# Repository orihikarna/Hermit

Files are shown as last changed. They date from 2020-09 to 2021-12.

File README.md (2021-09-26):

# Hermit - An Ergonomic Narrow-Pitch Split Keyboard

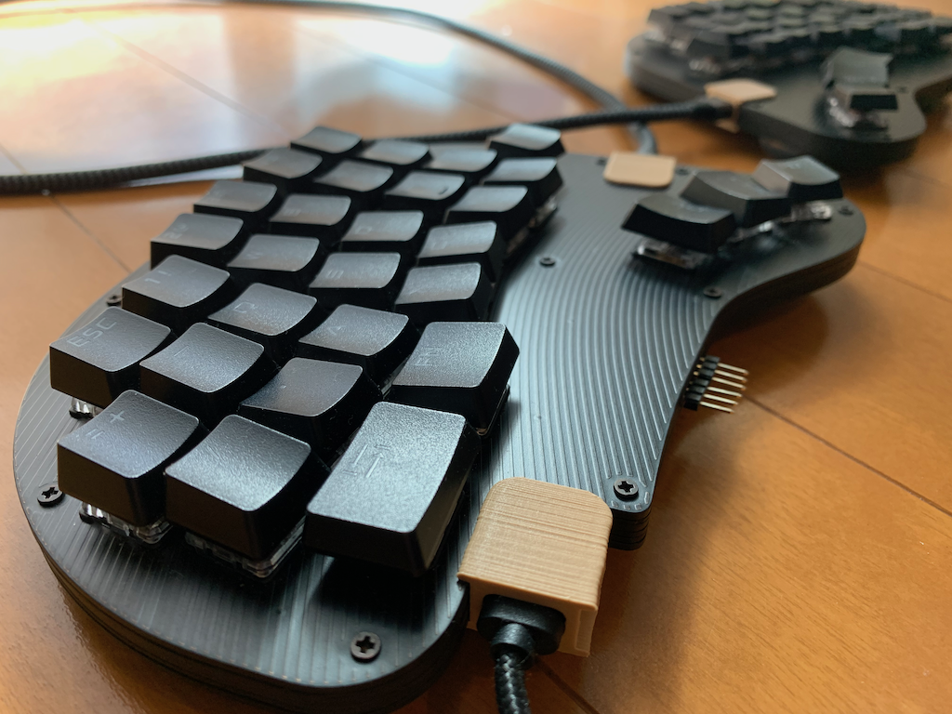
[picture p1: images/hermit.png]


## Introduction
This is a personal hobby project on DIY keyboard.
The name *Hermit* comes from its key switch layout: it looked like a hermit crab.

Before working on this "full" keyboard, I made a test split keypad with 10 keys as a proof of concept model, which was named *Zoea*.

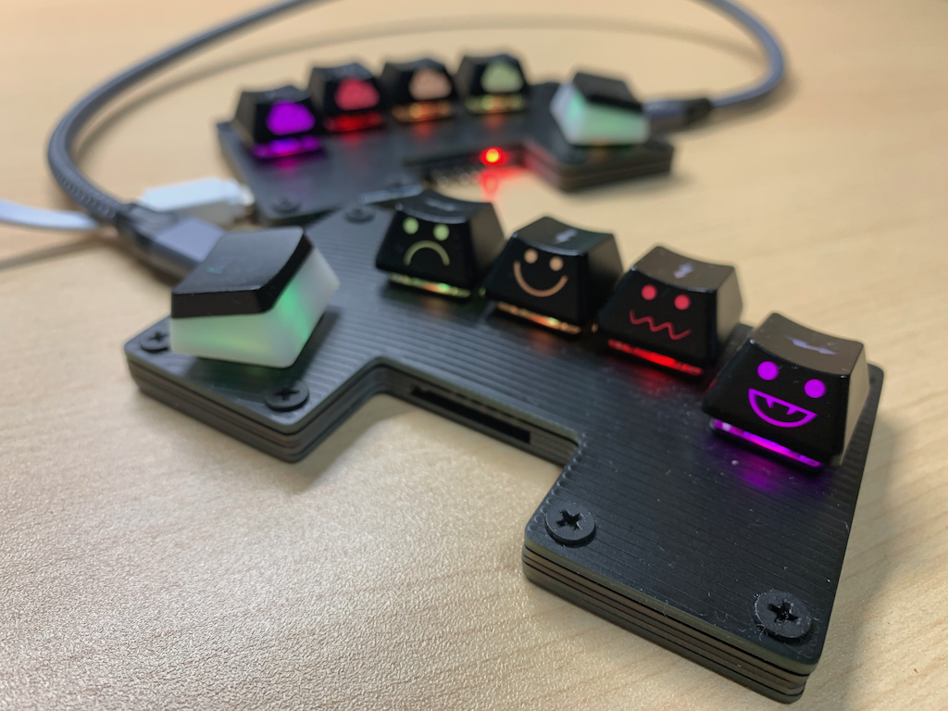
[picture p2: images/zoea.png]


### Features
- Symmetric split with 60 keys
  - Key switch: Choc V2
  - Narrow pitch: 17.4 x 16.8mm
  - Thumb keys placed a bit further (to press them with the first joint)
  - Full color RGB LED
- Controller
  - ARM (STM32F042K6T6)
  - I/O expander (MCP23017) via I2C (using USB Type-C cable)
  - Debounce RC circuit (firmware reads Col 1ms after writing Row)
- Firmware
  - C++ bare-metal (STM32CubeIDE)
  - Stream processing with FIFO's (no immediate sending of key presses/releases)
  - Emacs translation (ex. `C-d` -> `Del`)

## Key switch layout
Before assembling ErgoDash, I really liked the key touch of Realforce and had used it for a decade.
However, once I got used to ErgoDash, I could not go back to Realforce anymore because `B` key was too far for my left index finger.
In fact, I started feeling pain in the index finger after typing on Realforce for a day.

One day, I came across [Treadstone](https://booth.pm/ja/items/1434972) layout, where the `B` key, or the left half of the bottom row, is shifted to the left a bit.
I thought this is the answer for me and I should follow this design.

### Cardboard prototyping
To begin with, I placed keycaps on a cardboard with lines of double sided tapes on it, and try tapping on it.
Sometimes added more keys, and other times removed some of them to find one that suits my fingers.

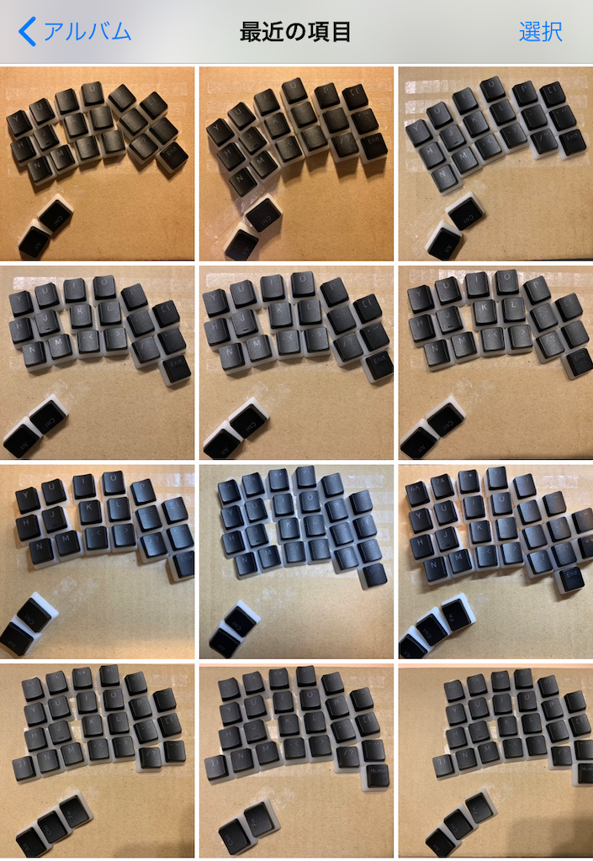
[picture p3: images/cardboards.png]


### 3D printer prototyping
After I purchased a 3D printer, I continued the seek for the layout using the actual Choc V2 key switches on 3D printed frames.
It enabled me to more finely adjust:
- Number of keys
- Key pitch: 17.0 ~ 18.0mm
- Key column positions and angles, especially for the thumbs

I usually use Japanese key layouts, and I found that 60 keys is the minimum that I can accept.
I wanted to keep most of the symbol keys on the board (without layers).

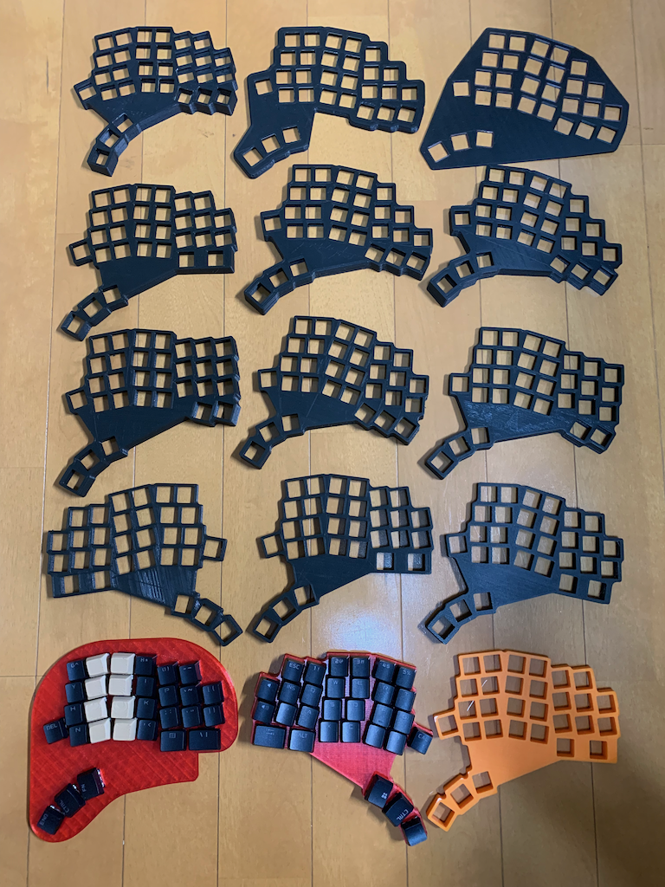
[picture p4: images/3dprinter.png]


### Parametric model
When the layout was roughly determined, I tried to parametrize the layout to adjust the degree of ergonomic-ness.
The strategies are:
- Ring finger keys are on a straight line
- `B` is a bit on the left of `G`
- Pinky finger keys are lower than ring finger keys
- Keys are tightly touching to each other

And finally settled down on the current layout.



## PCB Design
This keyboard is composed of 6 PCB layers and is 8mm thick in total.
- Top layer (1.6mm)
- Second top layer (0.8mm)
- Circuit layer (1.6mm, Left and Right)
- Mid layer (1.2mm x2)
- Bottom layer (1.6mm)

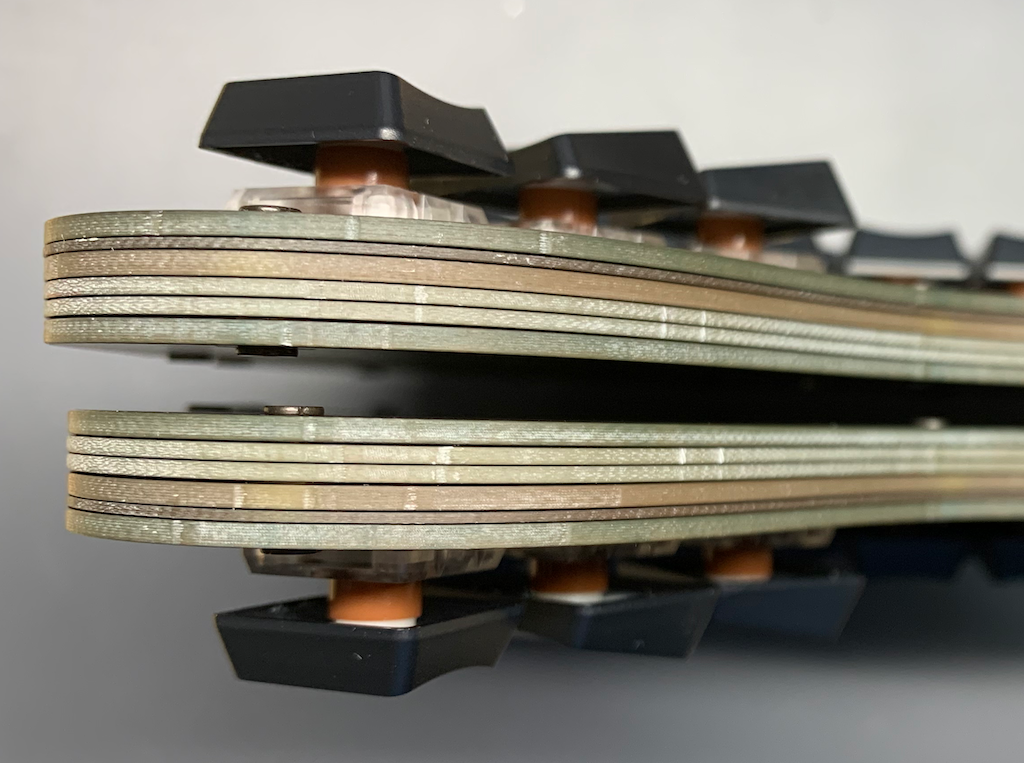
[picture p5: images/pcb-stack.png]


I used KiCad v5.1.5 for the PCB design.

### Top
- Supports key switches.
- Common to Left and Right (reversible).

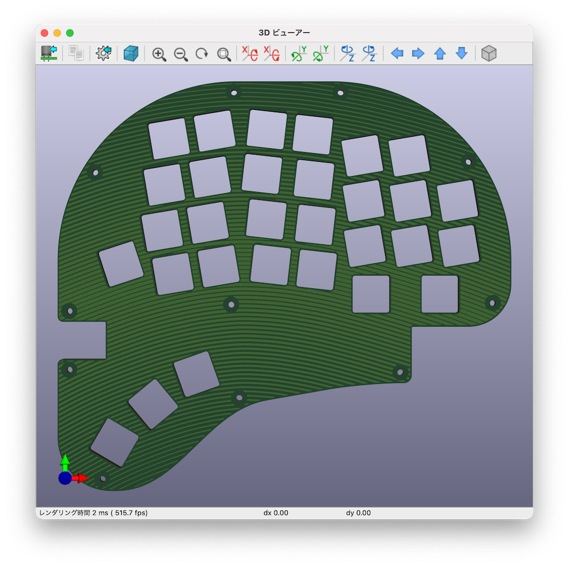
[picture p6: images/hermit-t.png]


### Second top
- Fills in the gap between the top plate and the bottom of the box part of the key switches.
- Gives holes for USB connecter terminals.
- Common to Left and Right.

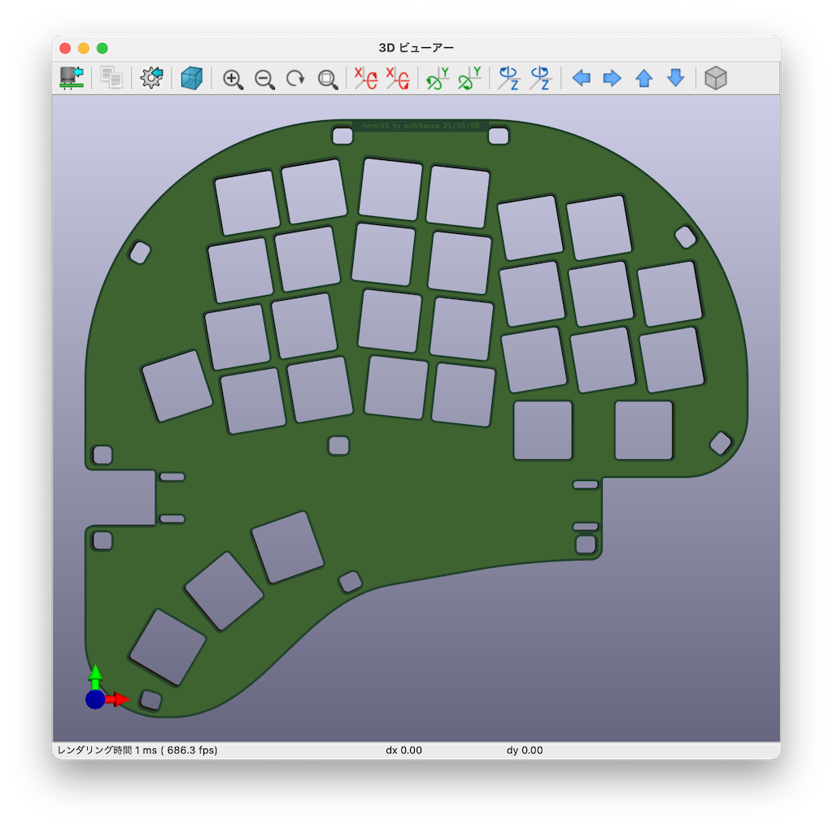
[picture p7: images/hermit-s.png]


#### Circuit Left & Right
- Implements the circuitry, and USB connecters.

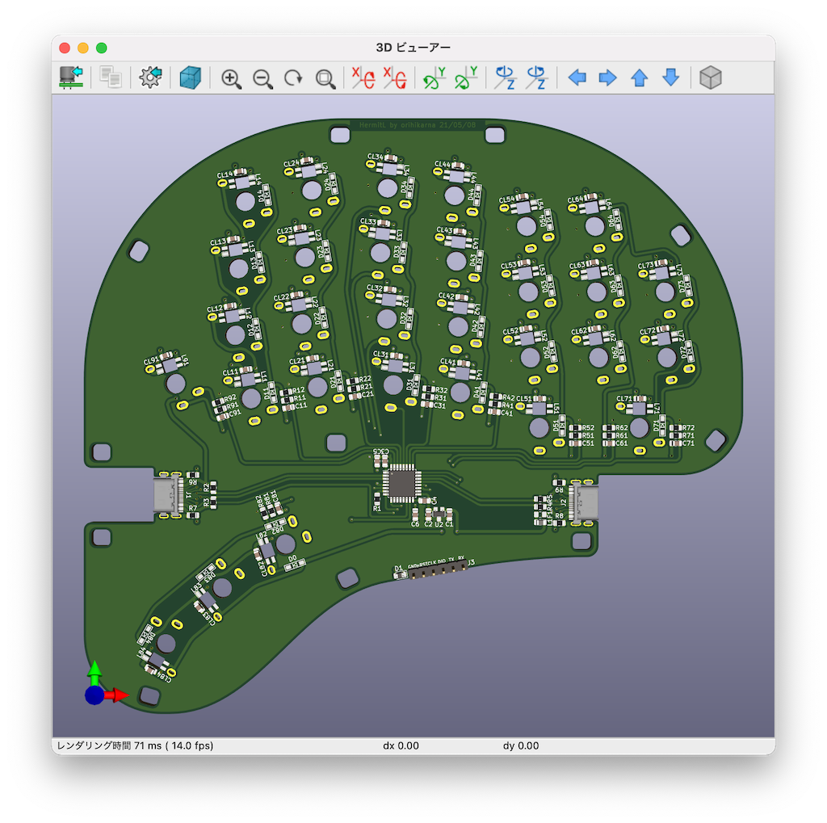
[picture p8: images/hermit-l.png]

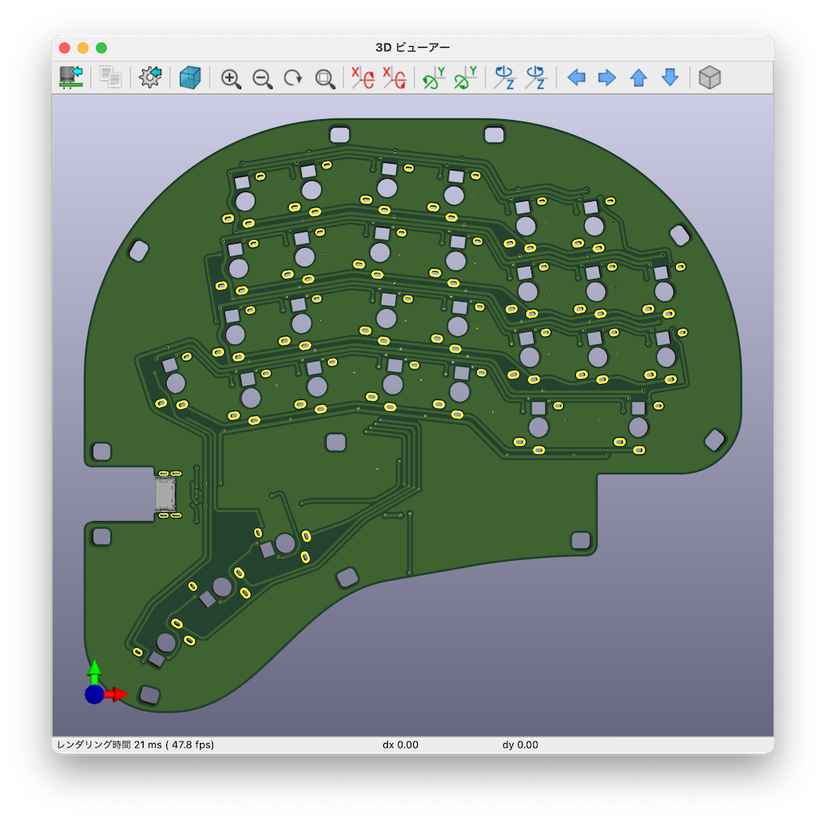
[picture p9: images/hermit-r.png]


#### Middle
- Fills in the gap between the bottom plate and the bottom of the axis part of the key switches.
- USB connecter island will be removed for Left.

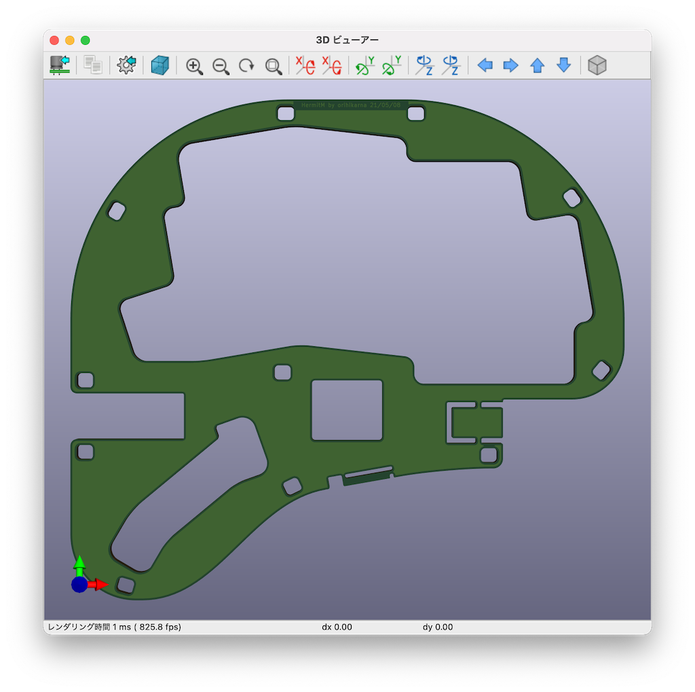
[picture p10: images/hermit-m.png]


#### Bottom
- Common to Left and Right.

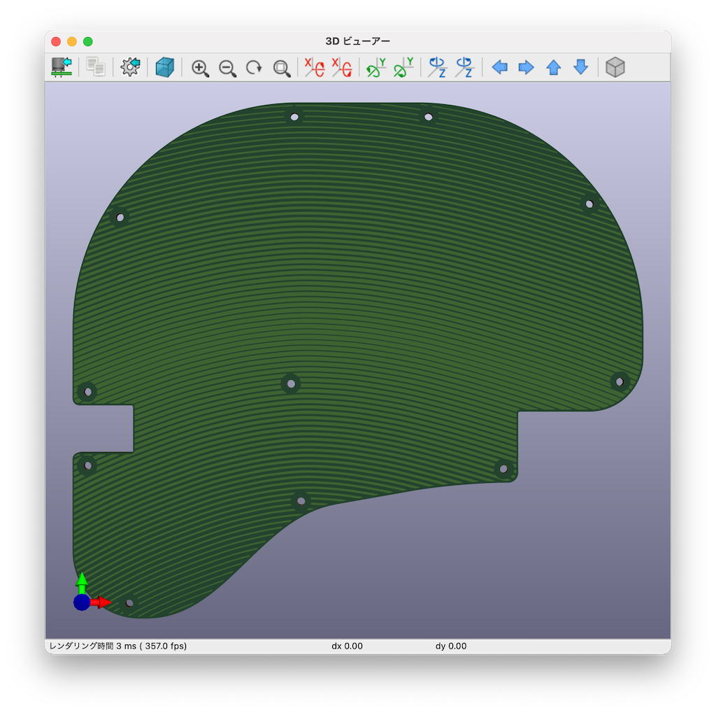
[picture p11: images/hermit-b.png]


### Place & route by Python script
All the footprint placement, wire routing, vias, silkscreen labels, Edge.Cuts and GND zones are done by a Python script.

Currently, only the component side (Front or Back) needs to be set manually first.
Then, from `Script Console` of Pcbnew layout editor, run
```
exec(open('/(your path)/Hermit/python/place-route-Hermit.py').read())
```
and everything will be done in seconds!
(Although it took 2 month for me to write the script, of course!)

For example, in the script, the wire from C21 (debounce capacitor) pad 1 to U1 (main mcu) pad 29 is written as:
```
            ('C21', '1', 'U1', '29', w_mcu, (Dird, 90, ([(5.8, 90)], 0), r_col)),
```
This means that:
- the wire width is w_mcu
- from C21 pad 1, extend wire in the direction of 90deg
- from U1 pad 29, draw a wire for 5.8mm in the 90deg direction, and then, extend it to the direction of 0deg
- the intersection of the two lines will automatically be found
- make corners round by radius r_col

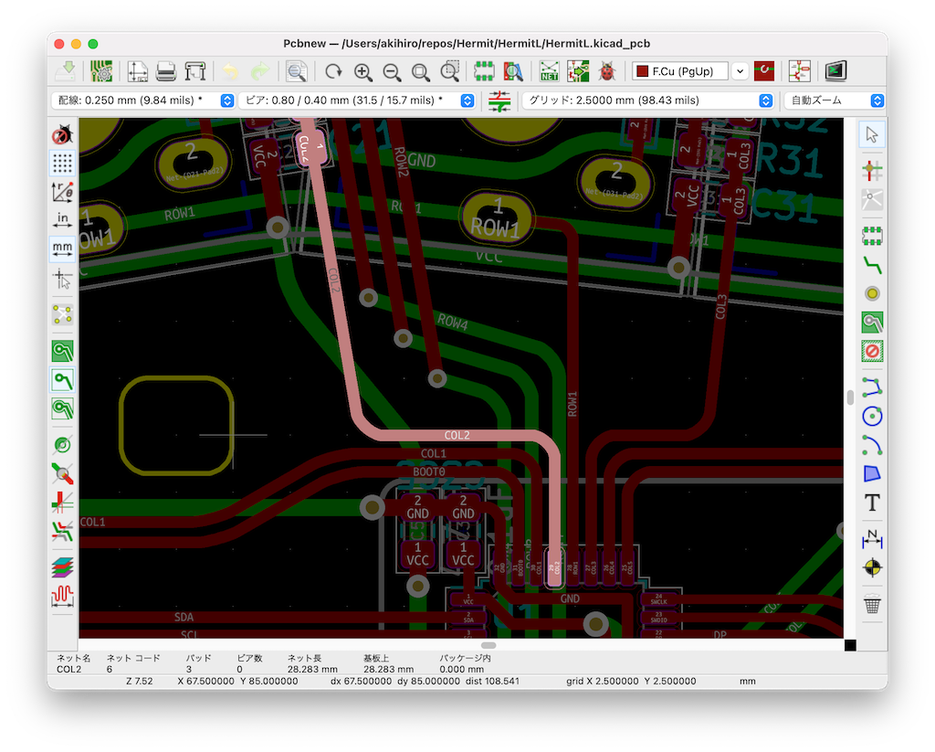
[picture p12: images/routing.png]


This way, the wiring is parallel to each part and looks roundy at corners.

## Debounce RC circuit
The mechanical key switches chatter sometimes.
Most DIY keyboards use software debouncing technique that comes with qmk (the standard keyboard firmware), where the key state (pressed or not) is examined twice with several milliseconds interval.
So, the switch bounce is hidden usually.
However, for the last two years, I experienced a couple of keys of my ErgoDash exhibited the chattering only in a specific season, i.e., in July or August in Japan.
I guess the software debounce might not be enough when it is very hot and super humid.
I've therefore added debounce RC for each column lines:

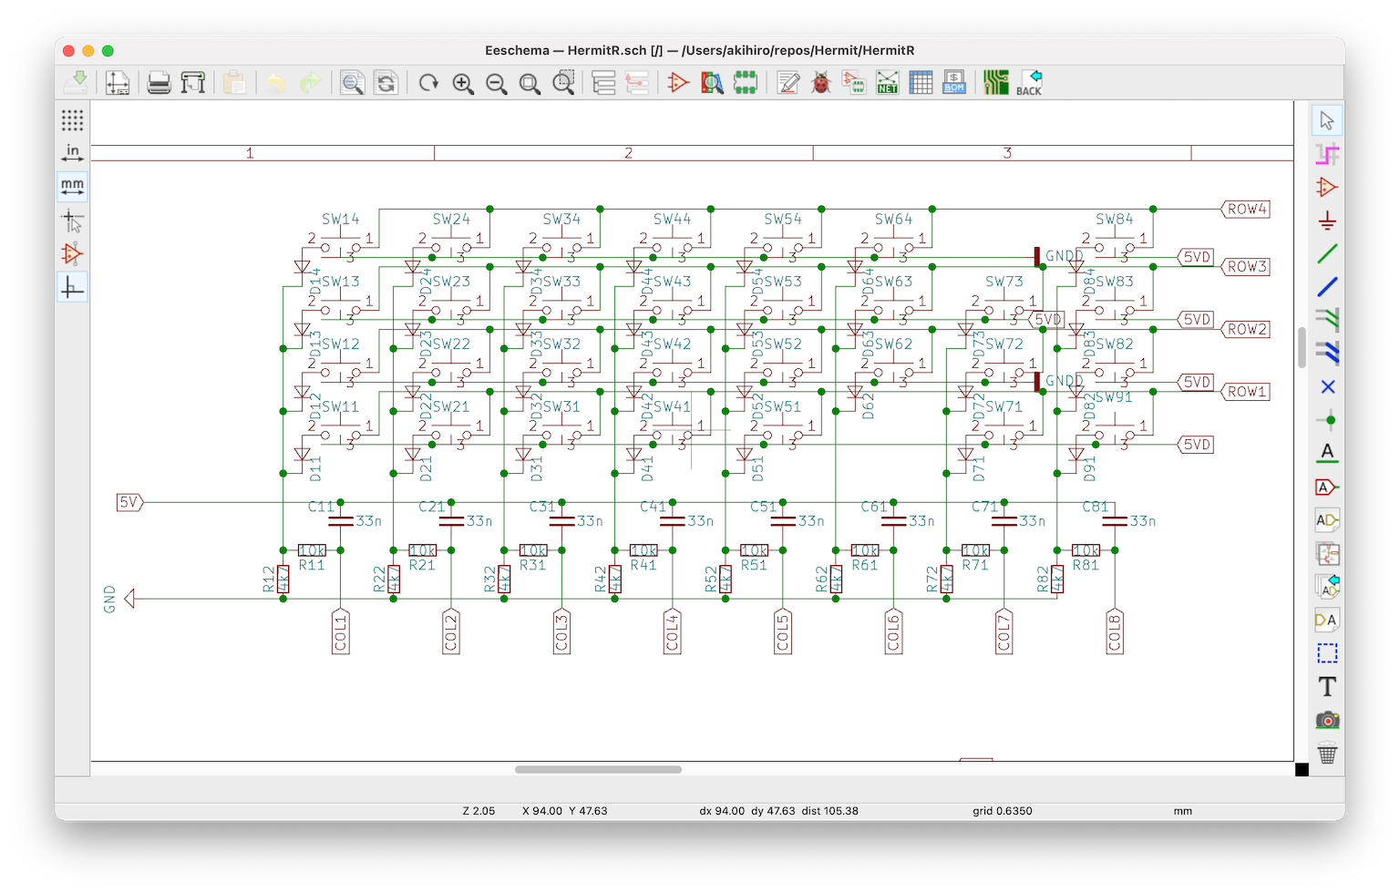
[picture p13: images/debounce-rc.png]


- When a key switch is released,
  - the Col lines are pulled down to GND.
  - the capacitors are fully charged.
- When a key switch is pressed,
  - the Row lines discharge the capacitors through key matrix diodes.
  - the Col lines rise to 5.0V or 3.3V minus 0.7V of the diode drop
- The time constant is different for discharging and charging, but they are set to about 1ms.
- Firmware needs to wait for 1~2ms before reading Col lines after writing Row lines.

I will check if this will actually contribute to reduce the switch bounce in the next summer!

For more information on hardware debounce, please refer to articles such as
[Ultimate Guide to Switch Debounce (Part 3)](https://www.eejournal.com/article/ultimate-guide-to-switch-debounce-part-3/)

## Rectangular holes for hexagon spacers
In Zoea PCB, it was useful to use hexagonal hole for spacers to keep them fixed: they won't rotate when tightening screws from the top and the bottom plates.
However, I needed to carefully choose the hexagon radius and the radius of the hexagon corners taking into account the endmill diameter.
So, this time, I used rectangular holes for the same purpose. I didn't have to consider much about the radius of the rectangle corners because any value would be fine with hexagon.

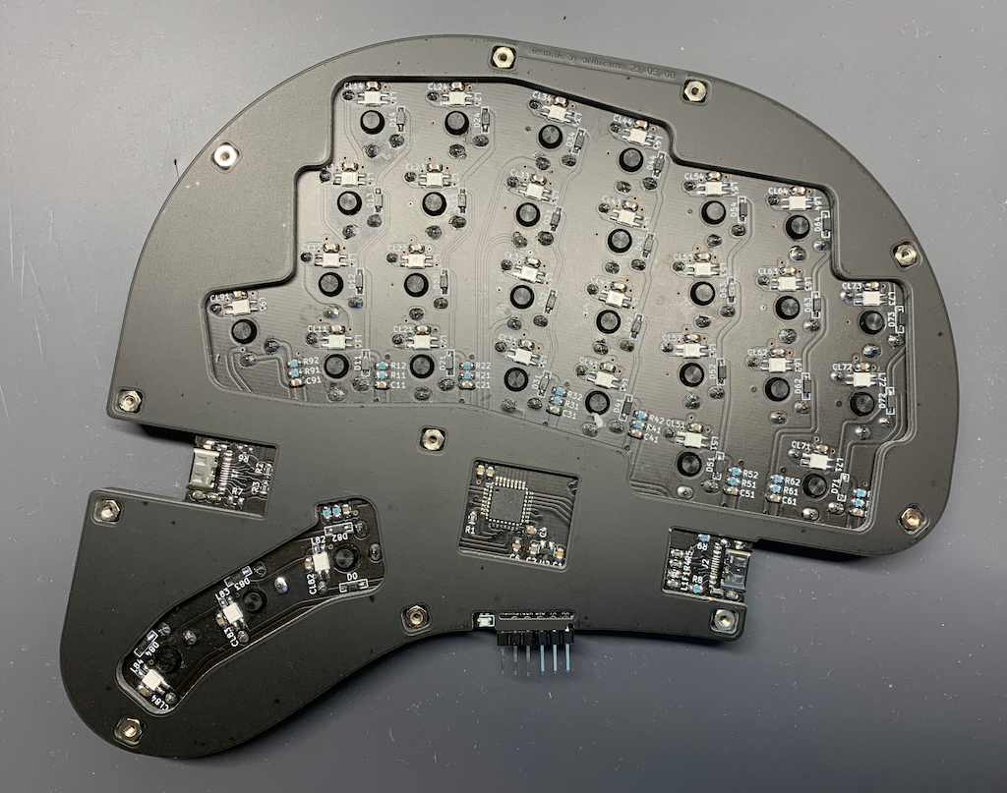
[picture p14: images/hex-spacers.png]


## Boundary avoidance using distance transform
I wanted to fill the surface of the top and the bottom plates with some design other than just nothing.
I'm not an artsy person at all, so I decided to draw simple stripes on them that curve along with the key switch angles.
The problem was that, how to end the stripe lines at the boundary of the board, screw holes, and of course the key switch holes. I didn't want that to happen all of a sudden abruptly.

So, I figured out a way to end lines just before the boundaries:
1. Export Edge.Cuts to svg (KiCad)
1. Rasterize svg to png (cairosvg Python package)
1. Binarize png to a mask image
1. Find connected components in the mask (OpenCV)
1. Choose the PCB component
1. Set initial distance (inside PCB = infinity, outside = 0)
1. Execute distance transform (OpenCV)

Then, you will get the distance from the boundaries.
It would be easier to end lines nicely at the boundaries: if it is near the boundary, you can use the distance value to find where to end the line.

The following figures are from Zoea top layer. First, the distance transform.

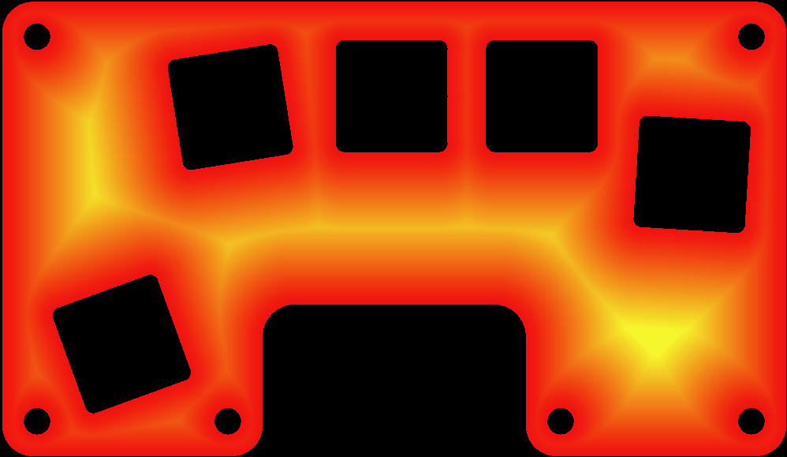
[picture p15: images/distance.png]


The final stripes on PCB. The thickness is reversed on its front and back.

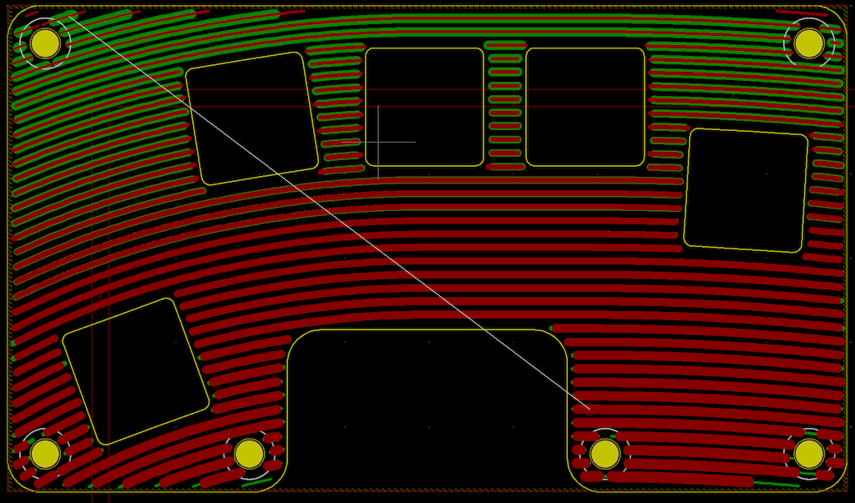
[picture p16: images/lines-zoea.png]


It looked ok that time, however, I wanted to get closer to the edge this time...
So, divided thick lines into a multiple of thin lines:

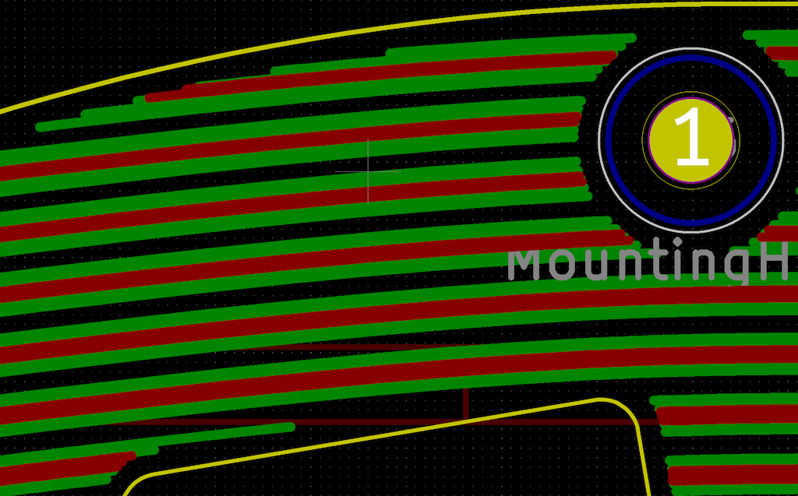
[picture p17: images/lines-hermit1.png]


and then, drew vertical / slant lines that connect the ends of thin horizontal lines:

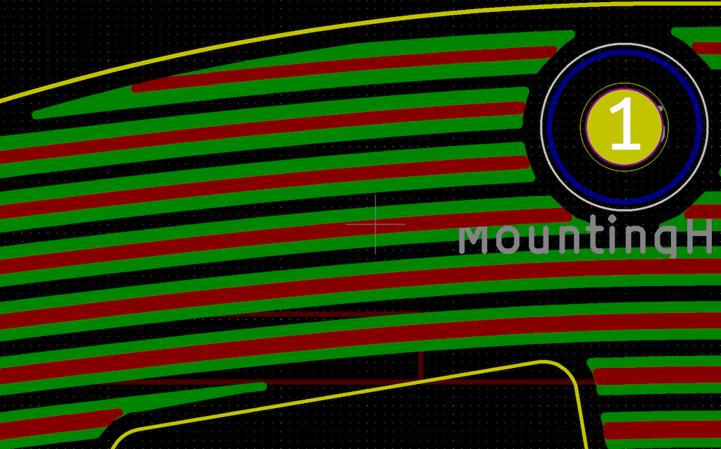
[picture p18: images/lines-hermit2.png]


## Firmware
For my studying of embedded programming, I wrote the firmware from scratch instead of using qmk.

### Stream processing
One thing I was thinking about qmk was register_code() and unregister_code() functions: these are used everywhere to send keycodes in the chain of processing.
However, since they send keycodes immediately, there is no room to to do more processing on the processed keycodes in the middle of the chain.

Of course, there are pros and cons.
But I wanted to try a stream structure, where each keycode processor is connected with FIFOs one after another to allow for successive processing.
Also, only one HID report will be prepared in the big loop that runs every 2ms.

A difficult part is the estimation of the required size for each FIFO.
If the FIFO size is too short, a processor in the chain cannot output anything and the entire stream would get stuck.

### Full Color RGB LED
At first, I placed LC8822-2020 on the key switch side of PCB.
They are good since they have separate data and clock lines (total 6 lines).
However, I noticed later that when they got broken, it is difficult to replace them because key switches are soldered above them.

Then, I decided to use SK6812-MINI-E, which is commonly used in DIY keyboards.
It has only one line for both data and clock, so it needs strict timing to send data.
There are 60 keys on Hermit, so that it takes 2ms to send series of data for all of them at once.
As 2ms felt too long, I split them to left and right half, and reduced the duration of interrupt-disabled periods to 1ms each.

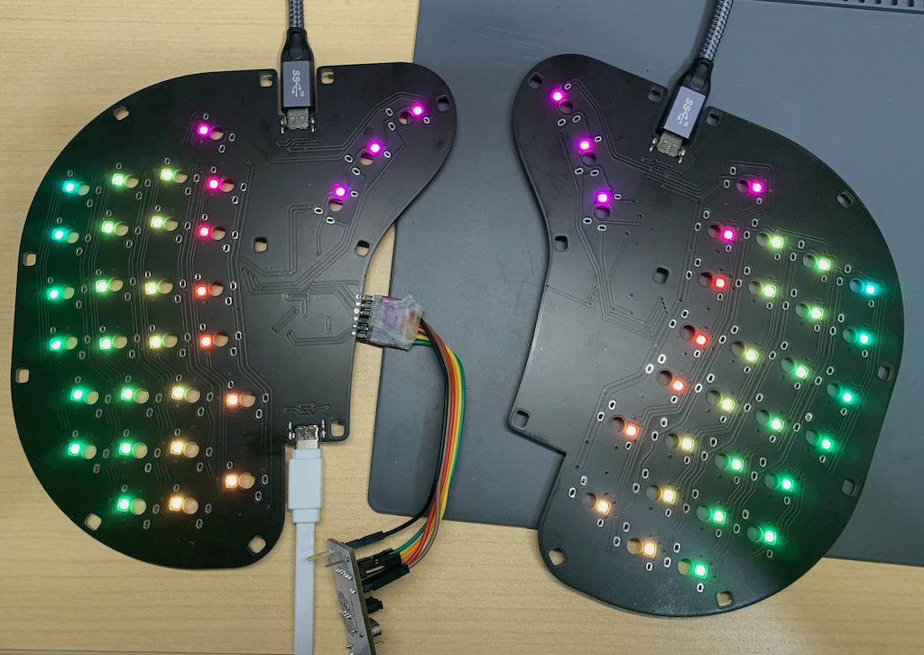
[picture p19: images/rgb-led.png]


### Emacs translation
I have been using Emacs key-binding for years.
There are ways to emulate it in a software manner on Windows, but what if it is inside a keyboard itself?

Although the current implementation needs tap & hold for single press of CTRL and ALT, other than that, it is working nicely!

### Minimizing the code size
At first, the code bloated with STM32 HAL USB library and printf (for debugging purpose) to more than 20KB.
However, thanks to STM32 LL library and the following libraries:
- [libusb_stm32](https://github.com/dmitrystu/libusb_stm32)
- [mini-printf](https://github.com/mludvig/mini-printf)

even after implemented RGB effects and Emacs translations, the current code size is:
- text: 16KB
- data+bss: 2.5KB

namely, only the half of STM32F042 capacity (32KB/6KB) is used.

## USB connector holders
For USB Type-C connectors, I gave up using the full 24-pin type due to the lack of my ability to solder them on PCB.
Instead, 16-pin type is used, where I2C is sent over D+/D- and LED signal is sent over SBU1/2.
Although other USB3.0 signal lines are not used at all, only because SBU1/2 is used, "full spec" Type-C cable is required to connect left and right.
They are thick in general and their stiffness gives strong forces on USB connectors.
So, I printed a simple-extrusion-work cable connector holder for them.
They need to be printed for each connector shape, but fit well and the cables are firmly attached to the keyboard.

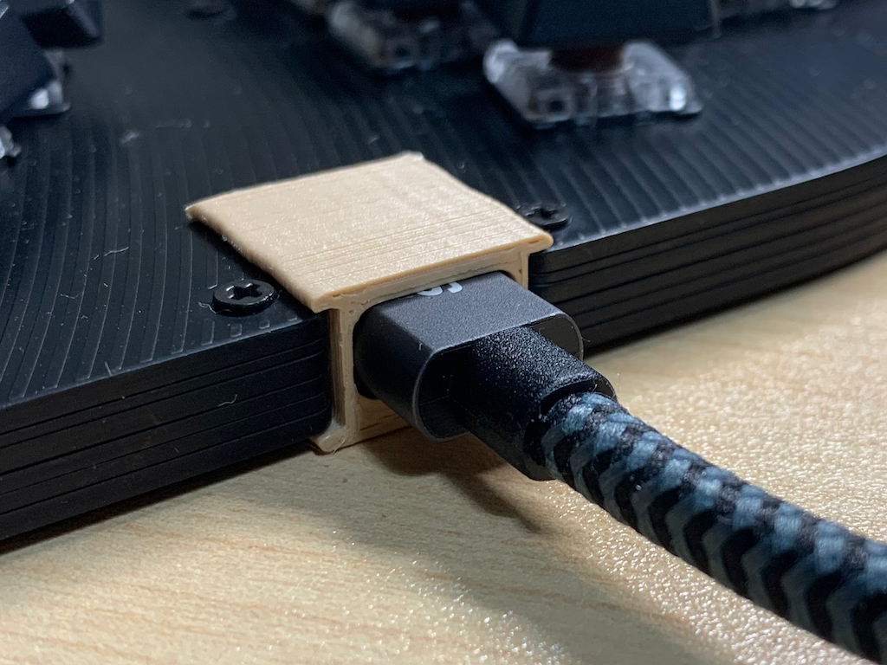
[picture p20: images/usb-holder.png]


## Finally, a short video
[Rainbow shaped Rainbow effect](https://twitter.com/orihikarna/status/1439446049446264836)



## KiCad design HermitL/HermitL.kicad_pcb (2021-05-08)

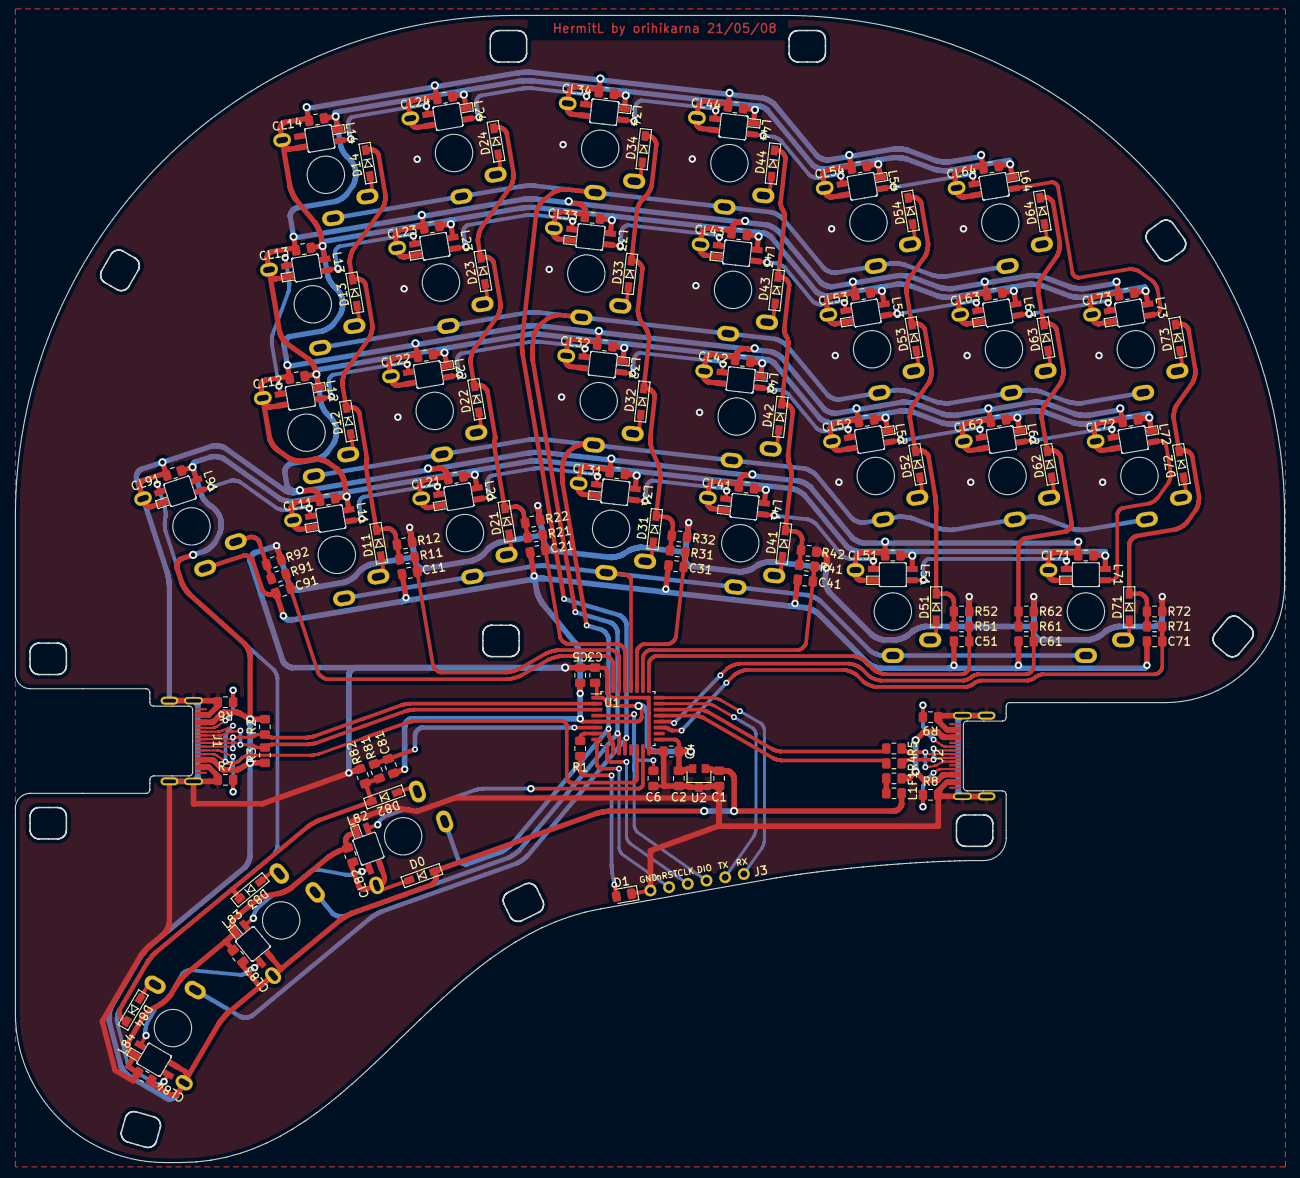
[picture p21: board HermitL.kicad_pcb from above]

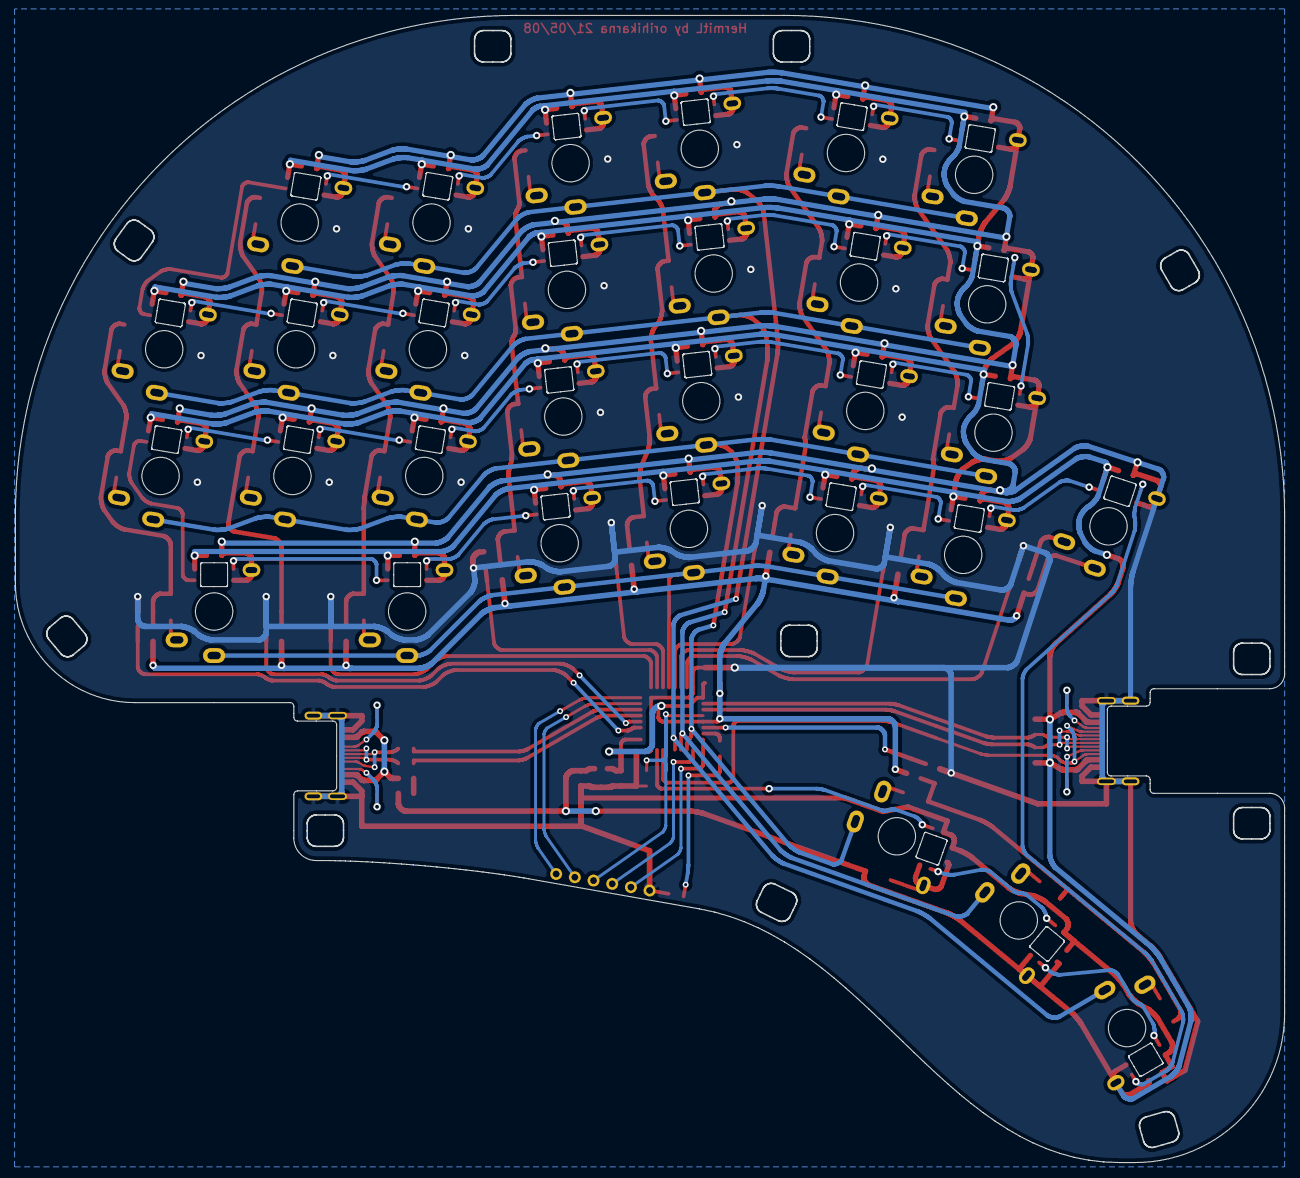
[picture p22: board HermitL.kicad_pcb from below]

Board: 2 copper layers, 169.9 x 153.6 mm, 170 parts (60 on the bottom side), 106 nets.

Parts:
C1: 1uF; C_0805_2012Metric_Pad1.15x1.40mm_HandSolder
C2: 10uF; C_0805_2012Metric_Pad1.15x1.40mm_HandSolder
C3, C4, C6: 0.1uF; C_0805_2012Metric_Pad1.15x1.40mm_HandSolder
C5: 4.7uF; C_0805_2012Metric_Pad1.15x1.40mm_HandSolder
C11, C21, C31, C41, C51, C61, C71, C81, C91: 33n; C_0805_2012Metric_Pad1.15x1.40mm_HandSolder
CL11, CL12, CL13, CL14, CL21, CL22, CL23, CL24, CL31, CL32, CL33, CL34, CL41, CL42, CL43, CL44, CL51, CL52, CL53, CL54, CL62, CL63, CL64, CL71, CL72, CL73, CL82, CL83, CL84, CL91: 0.1uF; C_0805_2012Metric_Pad1.15x1.40mm_HandSolder
D0, D11, D12, D13, D14, D21, D22, D23, D24, D31, D32, D33, D34, D41, D42, D43, D44, D51, D52, D53, D54, D62, D63, D64, D71, D72, D73, D82, D83, D84: D_Small; D_SMD
D1: LED; D_0805_2012Metric_Pad1.15x1.40mm_HandSolder
F1: Polyfuse; Fuse_0805_2012Metric_Pad1.15x1.40mm_HandSolder
J1, J2: USB_C_Receptacle_USB2.0; USB_C_Receptacle_Hirose_CX90M-16P
J3: Conn_01x06; PinHeader_1x06_P2.54mm_Vertical
L1: BLM21; L_0805_2012Metric_Pad1.15x1.40mm_HandSolder
L11, L12, L13, L14, L21, L22, L23, L24, L31, L32, L33, L34, L41, L42, L43, L44, L51, L52, L53, L54, L62, L63, L64, L71, L72, L73, L82, L83, L84, L91: SK6812-MINI-E
R1: 330; R_0805_2012Metric_Pad1.15x1.40mm_HandSolder
R2, R3: 2K2; R_0805_2012Metric_Pad1.15x1.40mm_HandSolder
R4, R5: 22; R_0805_2012Metric_Pad1.15x1.40mm_HandSolder
R6, R7, R8, R9: 5k1; R_0805_2012Metric_Pad1.15x1.40mm_HandSolder
R11, R21, R31, R41, R51, R61, R71, R81, R91: 10k; R_0805_2012Metric_Pad1.15x1.40mm_HandSolder
R12, R22, R32, R42, R52, R62, R72, R82, R92: 4k7; R_0805_2012Metric_Pad1.15x1.40mm_HandSolder
SW11, SW12, SW13, SW14, SW21, SW22, SW23, SW24, SW31, SW32, SW33, SW34, SW41, SW42, SW43, SW44, SW51, SW52, SW53, SW54, SW62, SW63, SW64, SW71, SW72, SW73, SW82, SW83, SW84, SW91: SW_ChocV2; ChocV2
U1: STM32F042K6Tx; LQFP-32_7x7mm_P0.8mm
U2: AP7333

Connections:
4V3: CL82.1, D0.1, L82.1, SW82.3
5V: C1.1, CL11.1, CL12.1, CL13.1, CL14.1, CL21.1, CL22.1, CL23.1, CL24.1, CL31.1, CL32.1, CL33.1, CL34.1, CL41.1, CL42.1, CL43.1, CL44.1, CL51.1, CL52.1, CL53.1, CL54.1, CL62.1, CL63.1, CL64.1, CL71.1, CL72.1, CL73.1, CL83.1, CL84.1, CL91.1, D0.2, J1.A4, J1.B4, L1.1, L11.1, L12.1, L13.1, L14.1, L21.1, L22.1, L23.1, L24.1, L31.1, L32.1, L33.1, L34.1, L41.1, L42.1, L43.1, L44.1, L51.1, L52.1, L53.1, L54.1, L62.1, L63.1, L64.1, L71.1, L72.1, L73.1, L83.1, L84.1, L91.1, R2.2, R3.2, SW12.3, SW14.3, SW22.3, SW24.3, SW32.3, SW34.3, SW42.3, SW44.3, SW52.3, SW54.3, SW62.3, SW64.3, SW72.3, SW83.3, SW84.3, U2.1
BOOT0: C91.1, R91.1, U1.31
COL1: C11.1, R11.1, U1.30
COL2: C21.1, R21.1, U1.29
COL3: C31.1, R31.1, U1.27
COL4: C41.1, R41.1, U1.26
COL5: C51.1, R51.1, U1.25
COL6: C61.1, R61.1, U1.20
COL7: C71.1, R71.1, U1.19
COL8: C81.1, R81.1, U1.6
DM: R4.2, U1.21
DP: R5.2, U1.22
GND: C1.2, C2.2, C3.2, C4.2, C5.2, C6.2, D1.1, J1.A1, J1.B1, J1.S1, J1.S2, J1.S3, J1.S4, J2.A1, J2.B1, J2.S1, J2.S2, J2.S3, J2.S4, J3.1, R6.2, R7.2, R8.2, R9.2, R12.1, R22.1, R32.1, R42.1, R52.1, R62.1, R72.1, R82.1, R92.1, U1.16, U1.32, U2.3
GNDD: CL11.2, CL12.2, CL13.2, CL14.2, CL21.2, CL22.2, CL23.2, CL24.2, CL31.2, CL32.2, CL33.2, CL34.2, CL41.2, CL42.2, CL43.2, CL44.2, CL51.2, CL52.2, CL53.2, CL54.2, CL62.2, CL63.2, CL64.2, CL71.2, CL72.2, CL73.2, CL82.2, CL83.2, CL84.2, CL91.2, L11.3, L12.3, L13.3, L14.3, L21.3, L22.3, L23.3, L24.3, L31.3, L32.3, L33.3, L34.3, L41.3, L42.3, L43.3, L44.3, L51.3, L52.3, L53.3, L54.3, L62.3, L63.3, L64.3, L71.3, L72.3, L73.3, L82.3, L83.3, L84.3, L91.3, SW11.3, SW13.3, SW21.3, SW23.3, SW31.3, SW33.3, SW41.3, SW43.3, SW51.3, SW53.3, SW63.3, SW71.3, SW73.3, SW91.3
LDI: L82.4, U1.15
LED: R1.1, U1.7
NRST: C6.1, J3.4, U1.4
unnamed: D1.2, R1.2
unnamed: D11.1, D12.1, D13.1, D14.1, R11.2, R12.2
unnamed: D11.2, SW11.2
unnamed: D12.2, SW12.2
unnamed: D13.2, SW13.2
unnamed: D14.2, SW14.2
unnamed: D21.1, D22.1, D23.1, D24.1, R21.2, R22.2
unnamed: D21.2, SW21.2
unnamed: D22.2, SW22.2
unnamed: D23.2, SW23.2
unnamed: D24.2, SW24.2
unnamed: D31.1, D32.1, D33.1, D34.1, R31.2, R32.2
unnamed: D31.2, SW31.2
unnamed: D32.2, SW32.2
unnamed: D33.2, SW33.2
unnamed: D34.2, SW34.2
unnamed: D41.1, D42.1, D43.1, D44.1, R41.2, R42.2
unnamed: D41.2, SW41.2
unnamed: D42.2, SW42.2
unnamed: D43.2, SW43.2
unnamed: D44.2, SW44.2
unnamed: D51.1, D52.1, D53.1, D54.1, R51.2, R52.2
unnamed: D51.2, SW51.2
unnamed: D52.2, SW52.2
unnamed: D53.2, SW53.2
unnamed: D54.2, SW54.2
unnamed: D62.1, D63.1, D64.1, R61.2, R62.2
unnamed: D62.2, SW62.2
unnamed: D63.2, SW63.2
unnamed: D64.2, SW64.2
unnamed: D71.1, D72.1, D73.1, R71.2, R72.2
unnamed: D71.2, SW71.2
unnamed: D72.2, SW72.2
unnamed: D73.2, SW73.2
unnamed: D82.1, D83.1, D84.1, R81.2, R82.2
unnamed: D82.2, SW82.2
unnamed: D83.2, SW83.2
unnamed: D84.2, SW84.2
unnamed: F1.2, L1.2
unnamed: J1.A5, R6.1
unnamed: J1.B5, R7.1
unnamed: J2.A5, R8.1
unnamed: J2.A6, J2.B6, R5.1
unnamed: J2.A7, J2.B7, R4.1
unnamed: J2.B5, R9.1
unnamed: L11.2, L21.4
unnamed: L11.4, L91.2
unnamed: L12.2, L13.4
unnamed: L12.4, L22.2
unnamed: L13.2, L23.4
unnamed: L14.4, L24.2
unnamed: L21.2, L31.4
unnamed: L22.4, L32.2
unnamed: L23.2, L33.4
unnamed: L24.4, L34.2
unnamed: L31.2, L41.4
unnamed: L32.4, L42.2
unnamed: L33.2, L43.4
unnamed: L34.4, L44.2
unnamed: L41.2, L51.4
unnamed: L42.4, L52.2
unnamed: L43.2, L53.4
unnamed: L44.4, L54.2
unnamed: L51.2, L71.4
unnamed: L52.4, L62.2
unnamed: L53.2, L63.4
unnamed: L54.4, L64.2
unnamed: L62.4, L72.2
unnamed: L63.2, L73.4
unnamed: L64.4, L73.2
unnamed: L71.2, L72.4
unnamed: L82.2, L83.4
unnamed: L83.2, L84.4
unnamed: L84.2, L91.4
unnamed: R91.2, R92.2, SW91.2
RDI: J1.A8, J1.B8, U1.14
ROW1: SW11.1, SW21.1, SW31.1, SW41.1, SW51.1, SW71.1, U1.28
ROW2: SW12.1, SW22.1, SW32.1, SW42.1, SW52.1, SW62.1, SW72.1, SW82.1, U1.10
ROW3: SW13.1, SW23.1, SW33.1, SW43.1, SW53.1, SW63.1, SW73.1, SW83.1, U1.11
ROW4: SW14.1, SW24.1, SW34.1, SW44.1, SW54.1, SW64.1, SW84.1, U1.12
RX: J3.3, U1.9
SCL: J1.A6, J1.B6, R3.1, U1.3
SDA: J1.A7, J1.B7, R2.1, U1.2
SWCLK: J3.6, U1.24
SWDIO: J3.5, U1.23
TX: J3.2, U1.8
VBUS: F1.1, J2.A4, J2.B4
VCC: C2.1, C3.1, C4.1, C5.1, C11.2, C21.2, C31.2, C41.2, C51.2, C61.2, C71.2, C81.2, C91.2, SW91.1, U1.1, U1.5, U1.17, U2.2

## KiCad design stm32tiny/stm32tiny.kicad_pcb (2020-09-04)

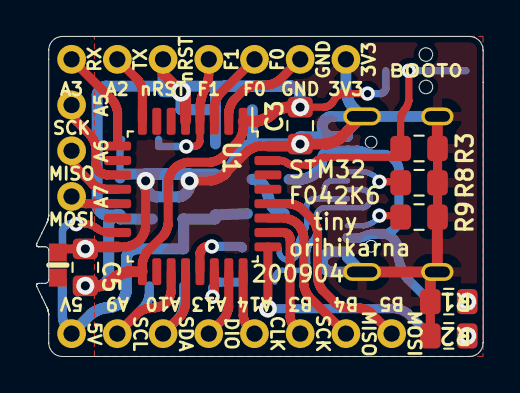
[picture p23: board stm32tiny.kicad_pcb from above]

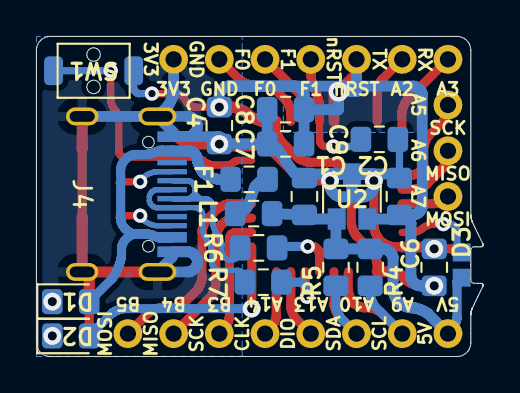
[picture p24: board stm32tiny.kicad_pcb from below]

Board: 2 copper layers, 24.8 x 17.8 mm, 30 parts (19 on the bottom side), 31 nets.

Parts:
C1, C8: 1uF; C_0805_2012Metric_Pad1.15x1.40mm_HandSolder
C2: 10uF; C_0805_2012Metric_Pad1.15x1.40mm_HandSolder
C3, C5, C9: 0.1uF; C_0805_2012Metric_Pad1.15x1.40mm_HandSolder
C4, C6: 4.7uF; C_0805_2012Metric_Pad1.15x1.40mm_HandSolder
C7: 0.01uF; C_0805_2012Metric_Pad1.15x1.40mm_HandSolder
D1: PW_LED; D_0805_2012Metric_Pad1.15x1.40mm_HandSolder
D2: LED; D_0805_2012Metric_Pad1.15x1.40mm_HandSolder
D3: SK6812-2020; WS2812B_2020_Vertical
F1: Polyfuse; Fuse_0805_2012Metric_Pad1.15x1.40mm_HandSolder
J1: Conn_01x08; PinHeader_1x08_P2.54mm_Vertical
J2: Conn_01x07; PinHeader_1x07_P2.54mm_Vertical
J3: Conn_01x03; PinHeader_1x03_P2.54mm_Vertical
J4: USB_C_Receptacle_USB2.0; USB_C_Receptacle_Neltron_5077CR
L1: BLM21; L_0805_2012Metric_Pad1.15x1.40mm_HandSolder
R1: 1K5; R_0805_2012Metric_Pad1.15x1.40mm_HandSolder
R2: 330; R_0805_2012Metric_Pad1.15x1.40mm_HandSolder
R3: 10K; R_0805_2012Metric_Pad1.15x1.40mm_HandSolder
R4, R5: 2K2; R_0805_2012Metric_Pad1.15x1.40mm_HandSolder
R6, R7: 22; R_0805_2012Metric_Pad1.15x1.40mm_HandSolder
R8, R9: 5k1; R_0805_2012Metric_Pad1.15x1.40mm_HandSolder
SW1: SW_Push; SW_SMD_5x3
U1: STM32F042K6Tx; LQFP-32_7x7mm_P0.8mm
U2: AP7333

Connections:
5V: C1.1, D3.4, J1.1, L1.1, R4.2, R5.2, U2.1
BOOT0: R3.1, SW1.2, U1.31
GND: C1.2, C2.2, C3.2, C4.2, C5.2, C6.2, C7.2, C8.2, C9.2, D3.2, J2.7, J4.A1, J4.B1, J4.S1, J4.S2, J4.S3, J4.S4, R1.2, R2.2, R3.2, R8.2, R9.2, U1.16, U1.32, U2.3
NRST: C9.1, J2.4, U1.4
unnamed: D1.1, R1.1
unnamed: D2.1, R2.1
unnamed: F1.2, L1.2
unnamed: J4.A5, R8.1
unnamed: J4.A6, J4.B6, R7.1
unnamed: J4.A7, J4.B7, R6.1
unnamed: J4.B5, R9.1
unnamed: R6.2, U1.21
unnamed: R7.2, U1.22
PA2: J2.2, U1.8
PA3: J2.1, U1.9
PA5: J3.1, U1.11
PA6: J3.2, U1.12
PA7: J3.3, U1.13
PA9: J1.2, R4.1, U1.19
PA10: J1.3, R5.1, U1.20
PA13: J1.4, U1.23
PA14: J1.5, U1.24
PA15: D2.2, U1.25
PB1: D3.3, U1.15
PB3: J1.6, U1.26
PB4: J1.7, U1.27
PB5: J1.8, U1.28
PF0: J2.6, U1.2
PF1: J2.5, U1.3
VBUS: D1.2, F1.1, J4.A4, J4.B4
VCC: C2.1, C3.1, C4.1, C5.1, C6.1, C7.1, C8.1, J2.3, SW1.1, U1.1, U1.5, U1.17, U2.2

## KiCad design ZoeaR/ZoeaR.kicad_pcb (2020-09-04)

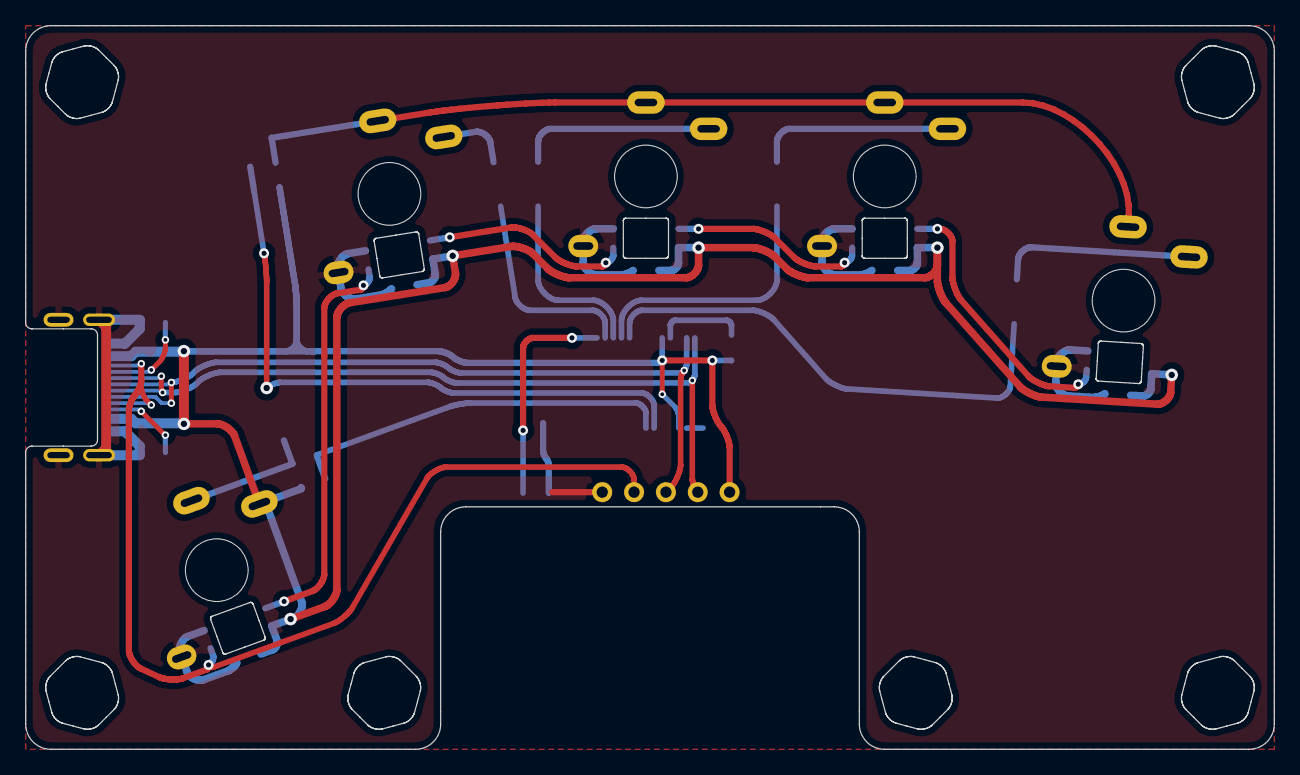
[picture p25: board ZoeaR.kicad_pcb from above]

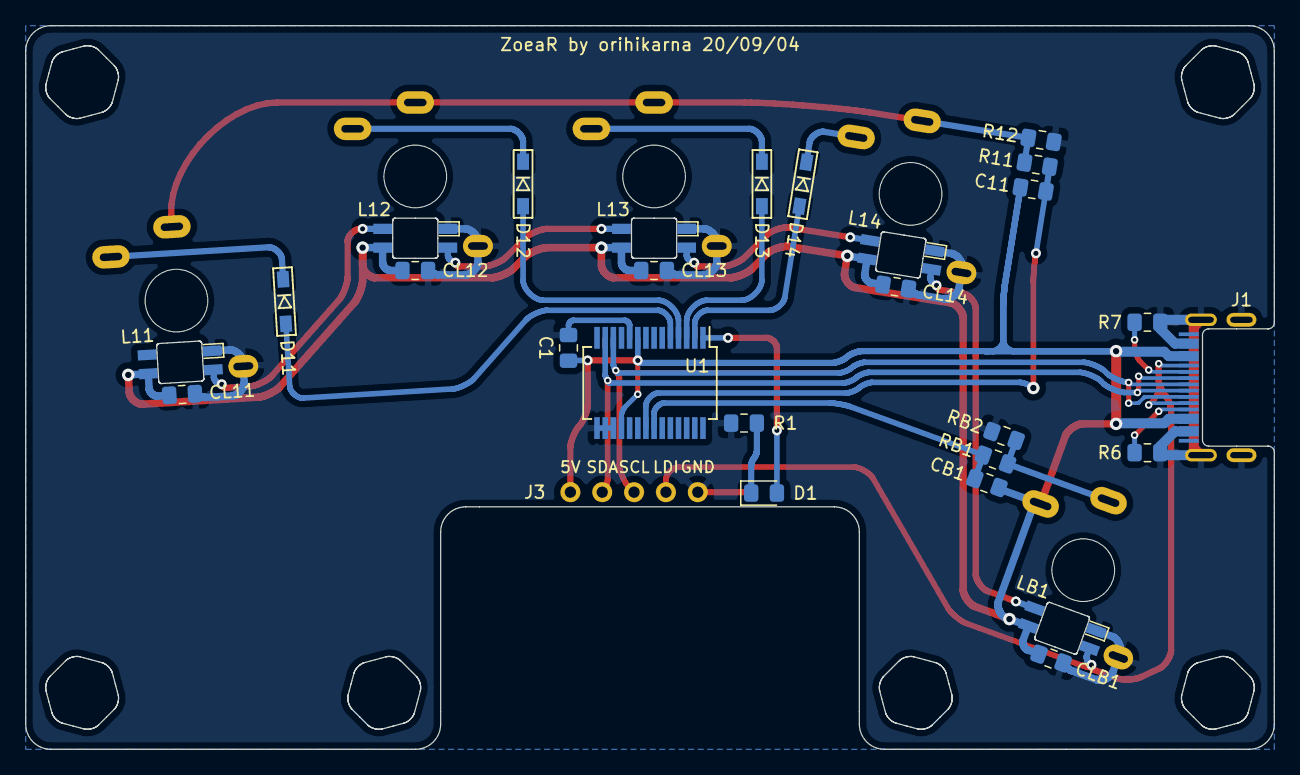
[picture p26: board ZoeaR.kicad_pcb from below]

Board: 2 copper layers, 99.6 x 57.7 mm, 33 parts (22 on the bottom side), 25 nets.

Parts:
C1: 0.1u; C_0805_2012Metric_Pad1.15x1.40mm_HandSolder
C11: 33n; C_0805_2012Metric_Pad1.15x1.40mm_HandSolder
CB1: 33n; C_0805_2012Metric_Pad1.15x1.40mm_HandSolder
CL11, CL12, CL13, CL14: 0.1u; C_0805_2012Metric_Pad1.15x1.40mm_HandSolder
CLB1: 0.1u; C_0805_2012Metric_Pad1.15x1.40mm_HandSolder
D1: LED; D_0805_2012Metric_Pad1.15x1.40mm_HandSolder
D11, D12, D13, D14: D_Small; D_SMD
J1: USB_C_Receptacle_USB2.0; USB_C_Receptacle_Hirose_CX90M-16P
J3: Conn_01x05; PinHeader_1x05_P2.54mm_Vertical
L11, L12, L13, L14: SK6812-MINI-E
LB1: SK6812-MINI-E
R1: 330; R_0805_2012Metric_Pad1.15x1.40mm_HandSolder
R6, R7: 5k1; R_0805_2012Metric_Pad1.15x1.40mm_HandSolder
R11: 10k; R_0805_2012Metric_Pad1.15x1.40mm_HandSolder
R12: 4k7; R_0805_2012Metric_Pad1.15x1.40mm_HandSolder
RB1: 10k; R_0805_2012Metric_Pad1.15x1.40mm_HandSolder
RB2: 4k7; R_0805_2012Metric_Pad1.15x1.40mm_HandSolder
SW11, SW12, SW13, SW14: SW_ChocV2; ChocV2
SWB1: SW_ChocV2; ChocV2
U1: MCP23017_SS; SSOP-28_5.3x10.2mm_P0.65mm

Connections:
5V: C1.1, C11.1, CB1.1, CL11.1, CL12.1, CL13.1, CL14.1, CLB1.1, J1.A4, J1.B4, J3.5, L11.1, L12.1, L13.1, L14.1, LB1.1, SWB1.2, U1.9, U1.18
BOOT0: CB1.2, RB1.2, U1.22
COL1: C11.2, R11.2, U1.21
GND: C1.2, CL11.2, CL12.2, CL13.2, CL14.2, CLB1.2, J1.A1, J1.B1, J1.S1, J1.S2, J1.S3, J1.S4, J3.1, L11.3, L12.3, L13.3, L14.3, LB1.3, R1.2, R6.2, R7.2, R12.2, RB2.2, SW11.3, SW12.3, SW13.3, SW14.3, SWB1.3, U1.10, U1.15, U1.16, U1.17
LDI: J1.A8, J1.B8, J3.2, LB1.4
LED: D1.2, U1.1
unnamed: D1.1, R1.1
unnamed: D11.1, SW11.2
unnamed: D12.1, SW12.2
unnamed: D13.1, SW13.2
unnamed: D14.1, SW14.2
unnamed: J1.A5, R6.1
unnamed: J1.B5, R7.1
unnamed: L11.4, L12.2
unnamed: L12.4, L13.2
unnamed: L13.4, L14.2
unnamed: L14.4, LB1.2
unnamed: R11.1, R12.1, SW11.1, SW12.1, SW13.1, SW14.1
unnamed: RB1.1, RB2.1, SWB1.1
ROW1: D11.2, U1.5
ROW2: D12.2, U1.4
ROW3: D13.2, U1.3
ROW4: D14.2, U1.2
SCL: J1.A6, J1.B6, J3.3, U1.12
SDA: J1.A7, J1.B7, J3.4, U1.13

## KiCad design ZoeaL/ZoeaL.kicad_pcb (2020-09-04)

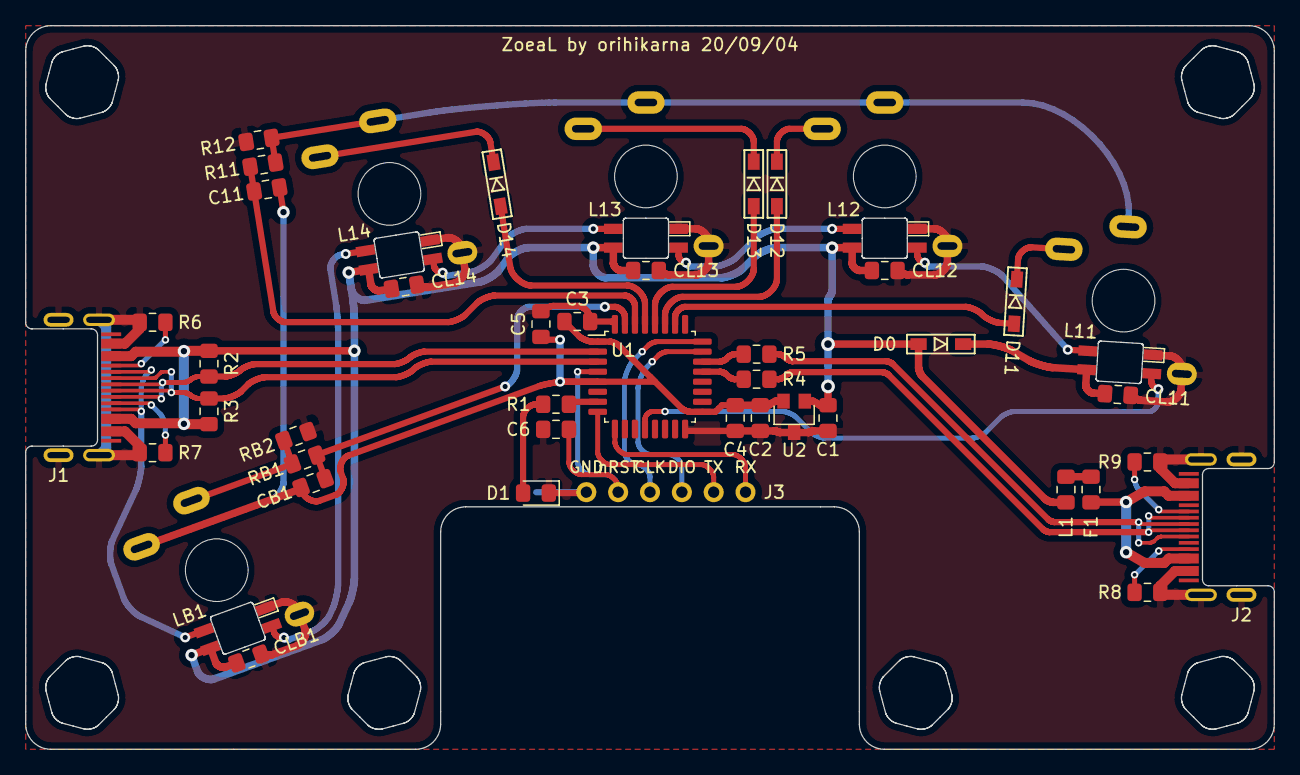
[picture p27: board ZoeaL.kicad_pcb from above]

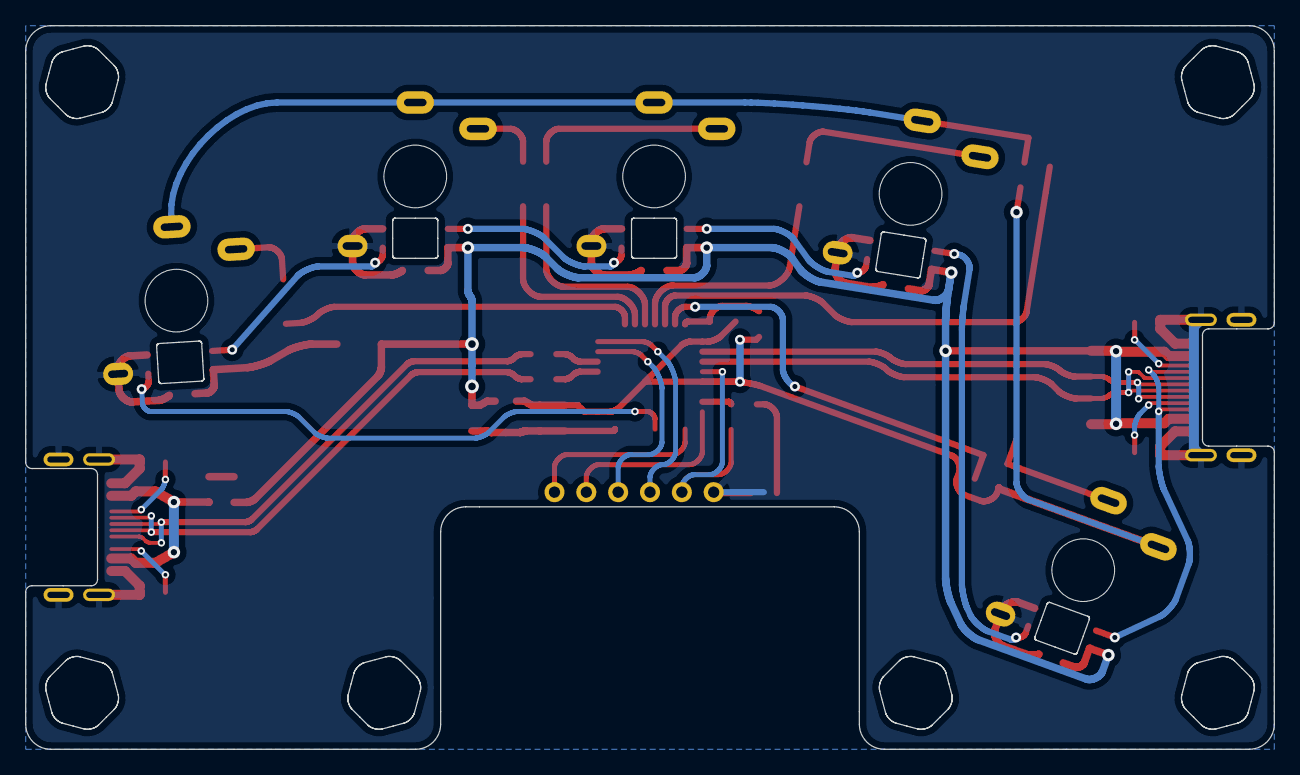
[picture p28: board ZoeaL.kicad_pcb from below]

Board: 2 copper layers, 99.6 x 57.7 mm, 49 parts (10 on the bottom side), 41 nets.

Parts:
C1: 1uF; C_0805_2012Metric_Pad1.15x1.40mm_HandSolder
C2: 10uF; C_0805_2012Metric_Pad1.15x1.40mm_HandSolder
C3, C4, C5, C6: 0.1uF; C_0805_2012Metric_Pad1.15x1.40mm_HandSolder
C11: 33n; C_0805_2012Metric_Pad1.15x1.40mm_HandSolder
CB1: 33n; C_0805_2012Metric_Pad1.15x1.40mm_HandSolder
CL11, CL12, CL13, CL14: 0.1uF; C_0805_2012Metric_Pad1.15x1.40mm_HandSolder
CLB1: 0.1uF; C_0805_2012Metric_Pad1.15x1.40mm_HandSolder
D0, D11, D12, D13, D14: D_Small; D_SMD
D1: LED; D_0805_2012Metric_Pad1.15x1.40mm_HandSolder
F1: Polyfuse; Fuse_0805_2012Metric_Pad1.15x1.40mm_HandSolder
J1, J2: USB_C_Receptacle_USB2.0; USB_C_Receptacle_Hirose_CX90M-16P
J3: Conn_01x06; PinHeader_1x06_P2.54mm_Vertical
L1: BLM21; L_0805_2012Metric_Pad1.15x1.40mm_HandSolder
L11, L12, L13, L14: SK6812-MINI-E
LB1: SK6812-MINI-E
R1: 330; R_0805_2012Metric_Pad1.15x1.40mm_HandSolder
R2, R3: 2K2; R_0805_2012Metric_Pad1.15x1.40mm_HandSolder
R4, R5: 22; R_0805_2012Metric_Pad1.15x1.40mm_HandSolder
R6, R7, R8, R9: 5k1; R_0805_2012Metric_Pad1.15x1.40mm_HandSolder
R11: 10k; R_0805_2012Metric_Pad1.15x1.40mm_HandSolder
R12: 4k7; R_0805_2012Metric_Pad1.15x1.40mm_HandSolder
RB1: 10k; R_0805_2012Metric_Pad1.15x1.40mm_HandSolder
RB2: 4k7; R_0805_2012Metric_Pad1.15x1.40mm_HandSolder
SW11, SW12, SW13, SW14: SW_ChocV2; ChocV2
SWB1: SW_ChocV2; ChocV2
U1: STM32F042K6Tx; LQFP-32_7x7mm_P0.8mm
U2: AP7333

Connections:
4V3: CL11.1, D0.1, L11.1
5V: C1.1, CL12.1, CL13.1, CL14.1, CLB1.1, D0.2, J1.A4, J1.B4, L1.1, L12.1, L13.1, L14.1, LB1.1, R2.2, R3.2, U2.1
BOOT0: CB1.2, RB1.2, U1.31
COL1: C11.2, R11.2, U1.30
GND: C1.2, C2.2, C3.2, C4.2, C5.2, C6.2, CL11.2, CL12.2, CL13.2, CL14.2, CLB1.2, D1.1, J1.A1, J1.B1, J1.S1, J1.S2, J1.S3, J1.S4, J2.A1, J2.B1, J2.S1, J2.S2, J2.S3, J2.S4, J3.1, L11.3, L12.3, L13.3, L14.3, LB1.3, R6.2, R7.2, R8.2, R9.2, R12.2, RB2.2, SW11.3, SW12.3, SW13.3, SW14.3, SWB1.3, U1.16, U1.32, U2.3
LDI: L11.4, U1.12
LDO: J1.A8, J1.B8, LB1.2
LED: R1.1, U1.7
NRST: C6.1, J3.2, U1.4
unnamed: D1.2, R1.2
unnamed: D11.1, SW11.2
unnamed: D12.1, SW12.2
unnamed: D13.1, SW13.2
unnamed: D14.1, SW14.2
unnamed: F1.2, L1.2
unnamed: J1.A5, R6.1
unnamed: J1.B5, R7.1
unnamed: J2.A5, R8.1
unnamed: J2.A6, J2.B6, R5.1
unnamed: J2.A7, J2.B7, R4.1
unnamed: J2.B5, R9.1
unnamed: L11.2, L12.4
unnamed: L12.2, L13.4
unnamed: L13.2, L14.4
unnamed: L14.2, LB1.4
unnamed: R4.2, U1.21
unnamed: R5.2, U1.22
unnamed: R11.1, R12.1, SW11.1, SW12.1, SW13.1, SW14.1
unnamed: RB1.1, RB2.1, SWB1.1
ROW1: D11.2, U1.26
ROW2: D12.2, U1.27
ROW3: D13.2, U1.28
ROW4: D14.2, U1.29
RX: J3.6, U1.9
SCL: J1.A6, J1.B6, R3.1, U1.3
SDA: J1.A7, J1.B7, R2.1, U1.2
SWCLK: J3.3, U1.24
SWDIO: J3.4, U1.23
TX: J3.5, U1.8
VBUS: F1.1, J2.A4, J2.B4
VCC: C2.1, C3.1, C4.1, C5.1, C11.1, CB1.1, SWB1.2, U1.1, U1.5, U1.17, U2.2

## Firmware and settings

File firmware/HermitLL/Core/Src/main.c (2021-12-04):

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
/* Includes ------------------------------------------------------------------*/
#include "main.h"

/* USER CODE BEGIN Includes */
#include "log.h"
#include "loop.hpp"
/* USER CODE END Includes */


/* USER CODE BEGIN PV */
volatile uint8_t g_timer_flag = 0;
volatile int16_t g_timer_counter = 0;
uint8_t s_led_state[2] = { 0, 0 };

void set_led_state( uint8_t index, uint8_t state ) {
  s_led_state[index] = state;
}
uint8_t get_led_state( uint8_t index ) {
  return s_led_state[index];
}
/* USER CODE END PV */

void SystemClock_Config(void);
static void MX_GPIO_Init(void);
static void MX_DMA_Init(void);
static void MX_I2C1_Init(void);
static void MX_TIM3_Init(void);
static void MX_USART2_UART_Init(void);
static void MX_TIM2_Init(void);
/* USER CODE BEGIN PFP */
void usb_setup();
void usb_loop();
/* USER CODE END PFP */

/* USER CODE BEGIN 0 */
#ifdef LOG_GLOBAL_ENABLE
void __io_putchar( uint8_t ch ) {
  while (LL_USART_IsActiveFlag_TXE( USART2 ) == 0);
  LL_USART_TransmitData8( USART2, ch );
}

int mini_puts( char*s, int len, void* buf ) {
  for (int n = 0; n < len; ++n) {
    __io_putchar( s[n] );
  }
  return len;
}

int mini_printf( const char* fmt, ... ) {
  va_list va;
  va_start( va, fmt );
  const int ret = mini_vpprintf( mini_puts, 0/*NULL*/, fmt, va );
  va_end( va );
  return ret;
}

#endif
/* USER CODE END 0 */

/**
  * @brief  The application entry point.
  * @retval int
  */
int main(void)
{
  /* MCU Configuration--------------------------------------------------------*/

  /* Reset of all peripherals, Initializes the Flash interface and the Systick. */

  LL_APB1_GRP2_EnableClock(LL_APB1_GRP2_PERIPH_SYSCFG);
  LL_APB1_GRP1_EnableClock(LL_APB1_GRP1_PERIPH_PWR);

  /* System interrupt init*/

  /* Configure the system clock */
  SystemClock_Config();

  /* Initialize all configured peripherals */
  MX_GPIO_Init();
  MX_DMA_Init();
  MX_I2C1_Init();
  MX_TIM3_Init();
#ifdef LOG_GLOBAL_ENABLE
  MX_USART2_UART_Init();
#endif
  MX_TIM2_Init();
  /* USER CODE BEGIN 2 */
  LL_SYSTICK_EnableIT();
  LL_TIM_EnableCounter( TIM2 );
  /* USER CODE END 2 */

  /* Infinite loop */
  /* USER CODE BEGIN WHILE */
  setup();
  usb_setup();
  while (1)
  {
    while (g_timer_flag == 0) {
      asm( "nop" );
    }
    g_timer_flag = 0;
    loop();
    //usb_loop();
    /* USER CODE END WHILE */

    /* USER CODE BEGIN 3 */
  }
  /* USER CODE END 3 */
}

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


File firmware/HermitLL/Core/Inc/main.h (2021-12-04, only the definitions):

#define COL8_Pin LL_GPIO_PIN_0
#define COL8_GPIO_Port GPIOA
#define LED_Pin LL_GPIO_PIN_1
#define LED_GPIO_Port GPIOA
#define ROW2_Pin LL_GPIO_PIN_4
#define ROW2_GPIO_Port GPIOA
#define ROW3_Pin LL_GPIO_PIN_5
#define ROW3_GPIO_Port GPIOA
#define ROW4_Pin LL_GPIO_PIN_6
#define ROW4_GPIO_Port GPIOA
#define RDI_Pin LL_GPIO_PIN_0
#define RDI_GPIO_Port GPIOB
#define LDI_Pin LL_GPIO_PIN_1
#define LDI_GPIO_Port GPIOB
#define COL7_Pin LL_GPIO_PIN_9
#define COL7_GPIO_Port GPIOA
#define COL6_Pin LL_GPIO_PIN_10
#define COL6_GPIO_Port GPIOA
#define COL5_Pin LL_GPIO_PIN_15
#define COL5_GPIO_Port GPIOA
#define COL4_Pin LL_GPIO_PIN_3
#define COL4_GPIO_Port GPIOB
#define COL3_Pin LL_GPIO_PIN_4
#define COL3_GPIO_Port GPIOB
#define ROW1_Pin LL_GPIO_PIN_5
#define ROW1_GPIO_Port GPIOB
#define COL2_Pin LL_GPIO_PIN_6
#define COL2_GPIO_Port GPIOB
#define COL1_Pin LL_GPIO_PIN_7
#define COL1_GPIO_Port GPIOB
#define COLB_Pin LL_GPIO_PIN_8
#define COLB_GPIO_Port GPIOB
#define NVIC_PRIORITYGROUP_0         ((uint32_t)0x00000007) /*!< 0 bit  for pre-emption priority,
#define NVIC_PRIORITYGROUP_1         ((uint32_t)0x00000006) /*!< 1 bit  for pre-emption priority,
#define NVIC_PRIORITYGROUP_2         ((uint32_t)0x00000005) /*!< 2 bits for pre-emption priority,
#define NVIC_PRIORITYGROUP_3         ((uint32_t)0x00000004) /*!< 3 bits for pre-emption priority,
#define NVIC_PRIORITYGROUP_4         ((uint32_t)0x00000003) /*!< 4 bits for pre-emption priority,

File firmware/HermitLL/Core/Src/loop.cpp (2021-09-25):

//#define LOG_LEVEL LL_ERROR
#include <array>
#include "main.h"
#include "keyscanner.hpp"
#include "keyproc.hpp"
#include "ledproc.hpp"
#include "loop.hpp"
#include "util.hpp"
#include "log.h"

namespace {

KeyScanner scanner;

std::array<KeyEvent, 12> keva_input;// 1 rows + extra
std::array<KeyEvent, 12> keva_layer;
std::array<KeyEvent, 12> keva_emacs;
std::array<KeyEvent,  6> keva_unmod;

KeyEventBuffer kevb_input( keva_input.data(), keva_input.size() );
KeyEventBuffer kevb_layer( keva_layer.data(), keva_layer.size() );
KeyEventBuffer kevb_emacs( keva_emacs.data(), keva_emacs.size() );
KeyEventBuffer kevb_unmod( keva_unmod.data(), keva_unmod.size() );

LedProc led_proc;
KeyLayerProc proc_layer;
KeyEmacsProc proc_emacs;
KeyUnmodProc proc_unmod;
KeyNkroProc  proc_nkro;

uint16_t cnt = 0;


void _setup()
{
  // key scanner
  scanner.init();
  led_proc.init();
  // processors
  proc_layer.init();
  proc_emacs.init();
  proc_unmod.init();
  proc_nkro.init();
}

void _loop()
{
  //if (_LL_GetTick() & 1) return;// 2ms loop
  cnt += 1;
  if (cnt & 1) return;// 2ms loop
  ElapsedTimer et;

  // key matrix scan
  scanner.scan( &kevb_input );
  led_proc.process( scanner.getSwitchStateData() );

  KeyEventBuffer* pkevb_in = nullptr;
  KeyEventBuffer* pkevb_out = &kevb_input;

# define _set_kevb( kevb ) pkevb_in = pkevb_out; pkevb_out = &kevb
  _set_kevb( kevb_layer ); while (proc_layer.process( *pkevb_in, *pkevb_out )) {}
  _set_kevb( kevb_emacs ); while (proc_emacs.process( *pkevb_in, *pkevb_out )) {}
  _set_kevb( kevb_unmod ); while (proc_unmod.process( *pkevb_in, *pkevb_out )) {}
# undef _set_kevb

  // send one event every 8ms
  if ((cnt & 0x07) == 0) {
    if (pkevb_out->can_pop()) {
      const auto kev = pkevb_out->pop_front();
      if (kev.m_event == EKeyEvent::Pressed) {
        //LOG_DEBUG( "%d, %d, %d", kev.m_code, kev.m_event, kev.m_tick_ms );
      }
      proc_nkro.send_key( kev );
    }
  }

  if (false && (cnt & 0x0fff) == 0) {
    LOG_DEBUG( "sys tick = %d", _LL_GetTick() );
    LOG_DEBUG( "max used input = %d", kevb_input.getMaxUsedSize() );
    LOG_DEBUG( "max used layer = %d", kevb_layer.getMaxUsedSize() );
    LOG_DEBUG( "max used emacs = %d", kevb_emacs.getMaxUsedSize() );
    LOG_DEBUG( "max used unmod = %d", kevb_unmod.getMaxUsedSize() );
  }
  LOG_ERROR( "elapsed = %ld us", et.getElapsedMicroSec() );
}

#if 0
void _loop2()
{
	const uint8_t sw = LL_GPIO_IsInputPinSet( COLB_GPIO_Port, COLB_Pin );
	const uint8_t led_on = ((cnt >> 8) & 1) ^ (sw);
	_LL_GPIO_SetOutputPinValue( LED_GPIO_Port, LED_Pin, led_on );
	if (sw && !prev_sw) {
		puts( "Hello World" );
	}
	prev_sw = sw;
	// LED
	if (true) {
	}
}
#endif
}

extern "C" {
void setup() {
	_setup();
}
void loop() {
	_loop();
}
}

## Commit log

2020-06-09 finished schematics, placed parts
    [stm32tiny.sch]
2020-06-11 more on wire_mods
2020-06-13 refactored wire_mods
2020-06-15 adjusted pcb size
2020-06-19 cleaning wire defs
2020-06-20 adjusted wires
2020-06-20 almost done wiring
2020-06-21 plot gerber 200621
    [stm32tiny.kicad_pcb]
2020-06-30 added LED wall, modified USB footprint
    [stm32tiny.sch]
2020-07-03 adjusting usb connector wiring
2020-07-05 Vcc zone, negative radius for Bezier wiring
2020-07-05 round wiring
2020-07-08 redid vias, round wire corners
2020-07-09 round wiring done
2020-07-10 adjusted references, wires
2020-07-23 ignore gerber files
2020-07-31 created ZoecaRight projct
    [ZoecaR.sch]
2020-08-02 renamed to ZoeaL
    [ZoeaL.sch]
2020-08-03 started p&r
    [ZoeaL.sch]
2020-08-07 roughly routed
    [ZoeaL.sch]
2020-08-09 drc, screw holes
    [ZoeaL.sch]
2020-08-10 adjusted led pin
    [ZoeaL.sch]
2020-08-12 hex holes
    [ZoeaL.kicad_pcb, ZoeaL.sch]
2020-08-13 created ZoeaR board
    [ZoeaR.sch, ZoecaR.sch]
2020-08-15 started p&r right side
    [ZoeaR.sch]
2020-08-15 added pass cap
    [ZoeaR.sch]
2020-08-17 roughly done
    [ZoeaR.sch]
2020-08-18 added top, mid, and bottom platex
    [ZoeaB.sch, ZoeaM.sch, ZoeaT.sch]
2020-08-20 wiring angle
    [ZoeaL.kicad_pcb, ZoeaR.sch]
2020-08-21 working on mid plate
    [ZoeaL.sch]
2020-08-22 making mid plate
2020-08-23 roughly done mid plate
2020-08-23 move references
    [ZoeaB.sch]
2020-08-24 fixed right board
2020-08-27 top plate lines
2020-08-29 top plate pattern
2020-08-29 stm32tiny to migrate to new wiring
    [stm32tiny.sch]
2020-08-30 cleaned ZoeaR
    [ZoeaL.sch, ZoeaR.sch]
2020-08-31 replacing LEDs
    [ZoeaL.sch]
2020-09-01 added LED caps
2020-09-02 redid right leds, moving diodes
2020-09-03 adjusted diode wiring
2020-09-03 replaced leds, added pass caps
    [ZoeaR.sch]
2020-09-03 led wiring, debounce positions
2020-09-04 added j3 to right board
    [ZoeaR.sch]
2020-09-04 200904 for submit
    [ZoeaB.kicad_pcb, ZoeaL.kicad_pcb, ZoeaM.kicad_pcb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]
2020-09-05 changed mid plate holes to edge.cuts for jlcpcb issue
    [ZoeaM.kicad_pcb]
2020-12-18 layout adjustments with 3D printer
2020-12-18 don't print keys for now
2021-02-24 created HermitL
    [HermitL.kicad_pcb, HermitL.sch]
2021-02-24 print for kicad
2021-03-01 adjusted keys offset, pcb size
2021-03-01 changed switch and diode connections
    [HermitL.sch]
2021-03-02 led ground, led placement
    [HermitL.sch]
2021-03-03 led routing
2021-03-08 changed thumb key direction, routing led
    [HermitL.sch]
2021-03-14 fixed SW71 connection
    [HermitL.sch]
2021-03-15 rough routing
    [HermitL.sch]
2021-03-16 adjusting led wires
2021-03-17 redid led wirings
2021-03-21 adusted row, col wires
2021-03-27 redoing mcu vcc, gnd
2021-03-30 alpha for left side wiring
2021-03-30 initiated Right side
    [HermitR.sch]
2021-04-01 ronting leds
    [HermitR.sch]
2021-04-01 routing led, row, diodes
    [HermitR.sch]
2021-04-02 wiring leds
    [HermitR.sch]
2021-04-03 wiring row, col lines
    [HermitR.sch]
2021-04-05 minor edit
    [HermitR.sch]
2021-04-15 refining wires, added mounting holes
    [HermitL.sch]
2021-04-16 redid wiring for left & right
    [HermitL.sch, HermitR.sch]
2021-04-25 fixed wires, screw holes
2021-04-26 added all board projects
    [HermitB.sch, HermitM.sch, HermitS.sch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]
2021-05-01 added distance image for top plate
2021-05-03 refined wiring for L, refs for L
2021-05-04 refined BDR wiring
2021-05-05 reduced screws
2021-05-05 fixing led pwr lines for L
2021-05-06 refined RGB power wires
2021-05-08 improved usb connector wiring
2021-05-08 plot gerbers
    [HermitB.kicad_pcb, HermitL.kicad_pcb, HermitM.kicad_pcb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]
2021-05-09 fixed keyswitch holes with Round option
    [HermitS.kicad_pcb]
2021-09-25 add symbols and footprints
2021-09-26 updated readme.md with usb connector
2021-12-04 right led on non-emacs mode

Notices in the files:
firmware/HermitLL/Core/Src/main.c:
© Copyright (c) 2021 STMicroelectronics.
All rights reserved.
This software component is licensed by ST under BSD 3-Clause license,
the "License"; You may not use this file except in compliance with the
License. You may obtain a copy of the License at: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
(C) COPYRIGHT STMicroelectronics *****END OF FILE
